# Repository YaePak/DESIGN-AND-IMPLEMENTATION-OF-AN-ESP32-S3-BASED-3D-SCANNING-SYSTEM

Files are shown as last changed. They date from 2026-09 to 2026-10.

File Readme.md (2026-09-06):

# 3D Scanner

## Project Overview

This project focuses on the design and development of a homemade 3D scanner using embedded hardware, distance sensors, motor control systems, and mechanical components.

The main objective is to build a low-cost scanning system capable of collecting distance information from a physical object and converting the collected measurements into three-dimensional data.

The scanner is designed to measure an object from multiple positions while controlling its mechanical movement. The collected measurements can later be processed into a point cloud and used for three-dimensional model reconstruction.

The project is inspired by existing homemade 3D scanner concepts but will be redesigned and developed based on our own hardware, software, mechanical structure, and system architecture.

---

## Why We Chose This Project

We chose the 3D Scanner project because 3D scanning is an interesting technology with practical applications in many fields, including manufacturing, reverse engineering, product design, digital modeling, and object measurement.

Commercial 3D scanners are often expensive and may require complex hardware and specialized software. Therefore, we wanted to explore whether a simpler and lower-cost system could be designed using commonly available components and embedded technology.

Another reason for choosing this project is the engineering challenge of achieving reliable results with limited hardware resources. The performance of the scanner depends not only on the distance sensor, but also on mechanical accuracy, motor positioning, measurement validation, and data processing.

Therefore, this project is not simply about building a scanner. It also provides an opportunity to investigate how hardware limitations, sensor accuracy, mechanical design, and software algorithms affect the quality of the final 3D model.

Our goal is to design and develop a functional prototype while understanding how different engineering components can work together to solve a real-world problem.

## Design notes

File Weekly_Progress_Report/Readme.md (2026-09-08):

# Project Weekly Progress Roadmap

## Project Title

**DESIGN AND IMPLEMENTATION OF AN ESP32-S3-BASED 3D OBJECT SCANNING SYSTEM**

This folder contains the weekly progress reports of the project.

The reports are organized according to the actual development progress of the team. Each week documents the completed tasks, individual responsibilities, current results, problems encountered, and the plan for the following week.

---

## Development Roadmap

### Week 1 – Research and Initial Design

- Research ESP32-S3
- Research Stepper Motor + A4988
- Research TF-Luna
- Develop the system operating principle and algorithm.
- Create the initial 3D mechanical design using Shapr3D.

---

### Week 2 – Hardware Setup and Sensor Testing

- Assemble hardware components
- Set up ESP32-S3 development environment
- Test TF-Luna sensor
- Test Stepper Motor + A4988
- Perform basic calibration and component testing

---

### Week 3 – Motion Control and System Integration

- Verify measurement accuracy and stability.
- Evaluate the sensor performance for 3D scanning.
- Integrate the sensor and motion control system.
- Implement the basic scanning sequence.
- Perform initial scanning tests.

---

### Week 4 – Data Collection and File Generation

- Collect distance and position data.
- Convert the scanning data into coordinate points.
- Generate and store the scanning data file in the ESP32-S3.
- Perform initial scanning tests.

---

### Week 5 – Wi-Fi File Transfer and Data Processing

- Implement Wi-Fi communication.
- Transfer the generated scanning file from the ESP32-S3 to a computer.
- Develop or test the PC-side data receiving process.
- Verify file integrity and scanning data.

---

### Week 6 – 3D Reconstruction

- Scan more complex objects.
- Process the collected point cloud.
- Apply noise filtering and outlier removal.
- Generate the 3D model and evaluate its accuracy.

---

### Week 7 – Final Report and System Testing

- Complete the final technical report.
- Perform complete system testing.
- Verify the overall system performance.
- Prepare the project for final presentation.

---

---

# Team Responsibilities

The project tasks are divided among three main members:

| Member | Student Number | Main Responsibilities |
|---|---|---|
| **Khoa** | 24119048 | Project planning, mechanical assembly, 3D printing, motion testing, Wi-Fi streaming, and 3D reconstruction |
| **Tài** | 24119080 | Electronic components, sensors, ESP32-S3 testing, data processing, filtering, and software documentation |
| **Tuấn** | 24119096 | System architecture, ESP32-S3, motor control, algorithms, and technical reporting | 

---

# Development Phases

The project is divided into the following main phases:

```text
Project Preparation
        ↓
Research and System Assembly
        ↓
Sensor Setup and Calibration
        ↓
Motion Control
        ↓
Sequential Scanning
        ↓
FreeRTOS Multi-Tasking
        ↓
Data Streaming
        ↓
Optimization
        ↓
3D Reconstruction
        ↓
System Validation and Final Report

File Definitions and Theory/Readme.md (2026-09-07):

# System Operating Principle and Algorithm

This section describes the **operating principle and algorithm** of the ESP32-S3-based 3D scanning system.

The system integrates three main components:

* **ESP32-S3** – Main controller of the system.
* **Stepper Motor and A4988 Driver** – Controls the rotational movement of the scanning mechanism.
* **TF-Luna ToF LiDAR Sensor** – Measures the distance between the sensor and the object.

During operation, the ESP32-S3 controls the stepper motor to rotate the object or scanning platform by predefined angular steps. At each position, the TF-Luna sensor measures the distance to the object's surface.

The ESP32-S3 collects and stores the corresponding **distance and angle data**. This process is repeated throughout the scanning cycle to obtain multiple points representing the object's surface.

The collected data can then be used for **Point Cloud Generation** and further **3D Object Reconstruction**.

## Basic Operating Flow

```text
Initialize System
        ↓
Move to Initial Position
        ↓
Rotate by Angular Step
        ↓
Measure Distance
        ↓
Store Distance + Angle
        ↓
Repeat Scanning Process
        ↓
Complete Scan
        ↓
Generate Point Cloud
        ↓
3D Reconstruction
```

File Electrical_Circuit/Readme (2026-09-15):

# PCB Design – ESP32-S3 3D Scanner

## 1. Overview

This section contains the PCB design for the **ESP32-S3-based 3D Scanning System**.

The PCB is designed to integrate the main control and interface circuits of the scanner, including:

* ESP32-S3 N16R8 development module
* 2× A4988 stepper motor drivers
* TF-Luna distance sensor
* Z-axis HOME button
* Power distribution and filtering components
* Motor and sensor connectors

The PCB is designed using **EasyEDA**.

---

## 2. Design Objectives

The main objectives of the PCB are:

* Provide a compact connection between the ESP32-S3 and peripheral modules.
* Control two stepper motors through A4988 drivers.
* Interface the TF-Luna distance sensor using UART.
* Provide a HOME function for the Z-axis.
* Separate motor power from logic power where necessary.
* Reduce wiring complexity compared with a breadboard prototype.
* Provide convenient connectors for motors, power, and external modules.

---

## 3. Main Components

| Component | Quantity | Function |
| --- | ---: | --- |
| ESP32-S3 N16R8 | 1 | Main controller |
| A4988 | 2 | Stepper motor drivers |
| Stepper motor  | 2 | Turntable and Z-axis movement |
| TF-Luna | 1 | Distance measurement |
| Tactile Button | 1 | Z-axis HOME function |
| LED | 1 | Status indication |
| Capacitors | As required | Power filtering |

---

## 4. GPIO Assignment

The current GPIO assignment is:

| Function | ESP32-S3 GPIO |
| --- | ---: |
| Turntable STEP | GPIO4 |
| Turntable DIR | GPIO5 |
| Turntable ENABLE | GPIO6 |
| Z-axis STEP | GPIO10 |
| Z-axis DIR | GPIO11 |
| Z-axis ENABLE | GPIO12 |
| HOME Button | GPIO7 |
| TF-Luna RX | GPIO17 |
| TF-Luna TX | GPIO18 |
| UART0 Debug | GPIO43 / GPIO44 |

### A4988 Control

#### Turntable

```text
ESP32-S3 GPIO4 → STEP
ESP32-S3 GPIO5 → DIR
ESP32-S3 GPIO6 → EN
```

#### Z-axis

```text
ESP32-S3 GPIO10 → STEP
ESP32-S3 GPIO11 → DIR
ESP32-S3 GPIO12 → EN
```

The `EN` input of the A4988 is active-low.

---

## 5. TF-Luna Interface

The TF-Luna is powered from the **5 V supply** and communicates with the ESP32-S3 through UART.

### TF-Luna Pin Connection

| TF-Luna Pin | Function | Connection |
| --- | --- | --- |
| 1 | +5V | 5V |
| 2 | RXD | ESP32-S3 GPIO18 (TX) |
| 3 | TXD | ESP32-S3 GPIO17 (RX) |
| 4 | GND | GND |
| 5 | Configuration | 3.3V / open for UART mode |
| 6 | Multiplexing output | NC |

UART signals are crossed between the sensor and ESP32-S3:

```text
TF-Luna TXD ─────→ ESP32-S3 GPIO17 (RX)
TF-Luna RXD ←───── ESP32-S3 GPIO18 (TX)
```

The TF-Luna power input is connected to the **5 V rail**, while the UART signals are connected to the ESP32-S3 GPIO pins.

---

## 6. Z-axis HOME Button

A tactile push button is used instead of a mechanical limit switch.

The button provides a manual HOME command:

```text
Press HOME button
       ↓
ESP32-S3 detects the button
       ↓
Z-axis moves toward the zero position
       ↓
Z position is set to 0
```

The button is connected using the ESP32-S3 internal pull-up:

```text
GPIO7 ───── Button ───── GND
```

Firmware configuration:

```cpp
pinMode(7, INPUT_PULLUP);
```

Therefore:

* Button released → `HIGH`
* Button pressed → `LOW`

No external pull-up resistor is required.

Software debounce can be implemented in firmware, so an external debounce capacitor is not required for the current design.

---

## 7. Power Design

The PCB contains separate power paths for logic and motors.

### ESP32-S3 / Logic

The ESP32-S3 and logic-level peripherals are supplied from the regulated logic supply.

### TF-Luna

```text
5V → TF-Luna Pin 1
GND → TF-Luna Pin 4
```

### A4988

The A4988 has two different power domains:

* `VDD` → logic supply
* `VMOT` → motor supply

The motor supply must **not** be connected directly to an ESP32-S3 GPIO.

A bulk capacitor should be placed close to the A4988 motor power input to reduce voltage transients generated by the stepper motor.

---

## 8. PCB Design in EasyEDA

The PCB design workflow is:

```text
Schematic
   ↓
Component Assignment
   ↓
PCB Layout
   ↓
Component Placement
   ↓
Routing
   ↓
Design Rule Check (DRC)
   ↓
3D Preview
   ↓
Gerber Generation
```

### Schematic

The schematic defines:

* ESP32-S3 connections
* A4988 control signals
* TF-Luna UART interface
* HOME button
* Power connections
* Motor connectors
* Decoupling and filtering components

### PCB Layout

Components are placed according to their electrical and mechanical requirements.

The A4988 drivers and motor connectors are positioned to keep high-current motor traces away from sensitive sensor and logic connections.

The TF-Luna interface is kept relatively close to the ESP32-S3 to simplify UART routing.

---

## 9. Routing Considerations

The following rules are considered during PCB routing:

* Keep motor power traces short and sufficiently wide.
* Keep GND connections low impedance.
* Place decoupling capacitors close to their corresponding power pins.
* Keep TF-Luna UART traces away from noisy motor power traces when possible.
* Avoid unnecessary long traces for STEP and DIR signals.
* Use a ground plane where appropriate.
* Keep the ESP32-S3 antenna area clear of copper and other components according to the module's layout requirements.

---

## 10. Design Verification

Before manufacturing, the PCB design should be checked for:

* Electrical connectivity
* Incorrect or missing connections
* Short circuits
* Unconnected pins
* GPIO conflicts
* Power polarity
* A4988 power connections
* TF-Luna UART TX/RX direction
* Connector pin assignments
* PCB Design Rule Check (DRC)

The final PCB should also be inspected using EasyEDA's 2D and 3D views before generating the Gerber files.

---

## 11. Tools

### PCB Design Software

**EasyEDA**

Used for:

* Schematic design
* PCB layout
* Component placement
* PCB routing
* Design Rule Check (DRC)
* 3D PCB visualization
* Gerber generation

### Main Development Platform

**ESP32-S3 N16R8**

Used as the main controller of the 3D scanner.

---

## 12. Project Status

Current PCB design includes:

* [x] ESP32-S3 interface
* [x] Two A4988 motor driver interfaces
* [x] TF-Luna UART interface
* [x] Z-axis HOME button
* [x] Power distribution
* [ ] Final PCB routing
* [ ] DRC verification
* [ ] 3D mechanical verification
* [ ] Gerber generation
* [ ] PCB fabrication
* [ ] Hardware testing

---

## 13. Directory Structure

```text
PCB/
├── README.md
├── Schematic/
├── PCB/
├── Gerber/
└── Documentation/
```

The `Schematic/` directory contains the circuit schematic, while the `PCB/` directory contains the EasyEDA PCB layout. Gerber files for manufacturing are stored separately in the `Gerber/` directory.

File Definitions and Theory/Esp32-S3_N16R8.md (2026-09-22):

# ESP32-S3 Microcontroller

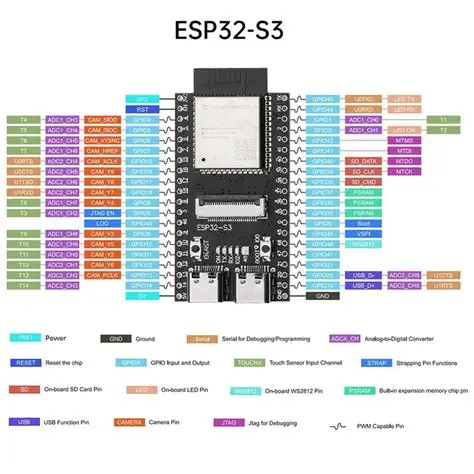
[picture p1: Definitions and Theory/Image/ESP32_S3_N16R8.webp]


The **ESP32-S3** is a high-performance microcontroller developed by Espressif Systems, designed for **IoT (Internet of Things)** and advanced embedded applications.

## Technical Specifications

* **CPU:** Dual-core Xtensa® LX7 processor
* **Clock Frequency:** Up to 240 MHz
* **Operating Voltage:** 3.0 V – 3.6 V (typically 3.3 V)
* **GPIO:** Up to 45 programmable GPIO pins
* **Wireless Connectivity:** Wi-Fi and Bluetooth Low Energy (BLE)
* **Interfaces:** UART, I2C, SPI, PWM, ADC, USB
* **USB:** Native USB support for programming and communication
* **Low-Power Modes:** Supported for energy-efficient applications

## Why ESP32-S3?

The ESP32-S3 was selected for this **3D Scanner project** because it provides high processing performance, a large number of GPIO pins, and multiple hardware interfaces required for connecting sensors and controlling motors.

Its dual-core processor allows the system to handle multiple tasks simultaneously, such as **sensor data acquisition, motor control, and communication**. In addition, the built-in Wi-Fi and BLE provide flexibility for wireless data transmission and remote control.

These features make the ESP32-S3 a suitable and cost-effective solution for developing a **3D object scanning system**.
# ESP32-S3 Microcontroller

The **ESP32-S3** is a high-performance microcontroller developed by Espressif Systems, designed for **IoT (Internet of Things)** and advanced embedded applications.

## Technical Specifications

* **CPU:** Dual-core Xtensa® LX7 processor
* **Clock Frequency:** Up to 240 MHz
* **Operating Voltage:** 3.0 V – 3.6 V (typically 3.3 V)
* **GPIO:** Up to 45 programmable GPIO pins
* **Wireless Connectivity:** Wi-Fi and Bluetooth Low Energy (BLE)
* **Interfaces:** UART, I2C, SPI, PWM, ADC, USB
* **USB:** Native USB support for programming and communication
* **Low-Power Modes:** Supported for energy-efficient applications

## Why ESP32-S3?

The ESP32-S3 was selected for this **3D Scanner project** because it provides high processing performance, a large number of GPIO pins, and multiple hardware interfaces required for connecting sensors and controlling motors.

Its dual-core processor allows the system to handle multiple tasks simultaneously, such as **sensor data acquisition, motor control, and communication**. In addition, the built-in Wi-Fi and BLE provide flexibility for wireless data transmission and remote control.

These features make the ESP32-S3 a suitable and cost-effective solution for developing a **3D object scanning system**.

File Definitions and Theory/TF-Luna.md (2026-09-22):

# Component Description — TF-Luna ToF LiDAR Sensor

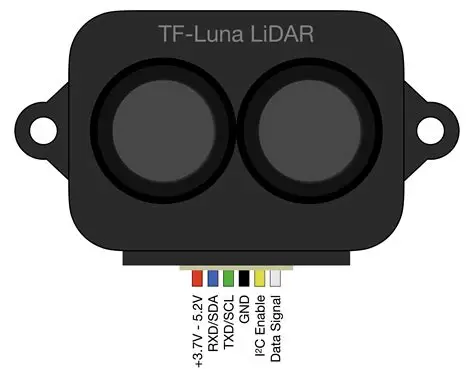
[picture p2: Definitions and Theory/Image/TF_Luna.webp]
TF_Luna


## What It Is

The TF-Luna is a compact, solid-state single-point LiDAR distance sensor made by Benewake. Unlike simple infrared (IR) distance sensors that estimate distance through triangulation of a reflected light spot, the TF-Luna uses the **Time-of-Flight (ToF) principle**: it emits a modulated near-infrared laser pulse and measures the time it takes for the light to reflect off a surface and return to the sensor. That time is then converted directly into a distance value.

## Technical Specifications

| Parameter | Value |
|---|---|
| Measuring principle | Time-of-Flight (ToF) |
| Light source | 850 nm VCSEL laser (Class 1 — eye-safe) |
| Operating range | 0.2 m – 8 m |
| Distance resolution | 1 cm |
| Accuracy | ±6 cm (0.2 m – 3 m), ±2% (3 m – 8 m) |
| Field of View (FOV) | 2° |
| Frame rate | 1 Hz – 250 Hz (100 Hz default, adjustable) |
| Supply voltage | 3.7 V – 5.2 V (5 V typical) |
| Average / peak current | ~70 mA / 150 mA |
| Power consumption | ≤ 0.35 W |
| Communication interface | UART or I2C (UART is the default; I2C must be set manually) |
| Communication level | LVTTL, 3.3 V (directly compatible with ESP32-S3 logic) |
| Default UART baud rate | 115200 |
| Dimensions / weight | 35 × 21.25 × 13.5 mm, < 5 g |
| Operating temperature | −20 °C to 75 °C |

## Why TF-Luna Fits This 3D Scanner Project

The scanner's design compares an IR distance sensor against a ToF sensor as part of its sensor sub-study, and TF-Luna is the ToF side of that comparison:

- **Consistent accuracy over the working range** — because it measures actual light travel time rather than triangulating a reflected spot, its accuracy stays relatively stable across the 0.2 m–8 m range and is less affected by the color or reflectivity of the scanned object's surface than a basic IR sensor is.
- **Narrow 2° field of view** — helps the sensor pick out a single, well-defined point on the object at each turntable angle/Z-height, which matters for building a clean point cloud.
- **Digital UART/I2C output** — the sensor returns a ready-to-use distance value over UART or I2C, so the ESP32-S3 doesn't need to do analog-to-digital conversion or apply a distance-conversion formula, unlike a typical analog IR sensor.
- **Low power and small footprint** — at under 0.35 W and 5 g, it is easy to mount on the scanner's moving Z-axis arm without adding significant load.
- **3.3 V-compatible logic level** — its LVTTL communication level matches the ESP32-S3 directly, simplifying wiring compared to sensors that need level shifting.

In the project's IR-vs-ToF comparison, TF-Luna represents the higher-accuracy, more consistent option, while the IR sensor represents the lower-cost, simpler-interface alternative — letting the report evaluate the practical trade-off between the two for a DIY 3D scanning application.

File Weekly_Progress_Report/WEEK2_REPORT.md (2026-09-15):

## TASKS FOR THIS WEEK

### 1. Adjustment and Improvement of the Mechanical Frame

- Inspect and adjust the mechanical frame to ensure that it is suitable for the object scanning process.
- Optimize the mounting positions of components and mechanical parts to ensure system stability during operation.
- Check the dimensions, structural strength, and movement of the mechanical mechanisms.
- Prepare the mechanical frame for system assembly and 3D scanning tests.

### 2. Component Testing and PCB Soldering

- Inspect the condition and specifications of the components before assembly.
- Test the functionality of the components to identify any defective or unsuitable components.
- Solder the components onto the PCB according to the circuit design.
- Inspect the quality of the solder joints and the connections between the components and the PCB after soldering.
- Perform an initial inspection and functional test of the PCB to ensure that it operates properly and is ready for system integration.

### Objectives

Complete and optimize the mechanical frame to meet the requirements of object scanning, while completing component testing and PCB assembly to prepare for the system integration, operation, and testing phase.

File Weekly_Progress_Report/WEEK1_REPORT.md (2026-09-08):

# 3. Member Responsibilities and Completed Tasks

## Huynh Anh Tuan - 24119096 – ESP32-S3 and System Control

### Assigned Tasks

- Research the ESP32-S3 microcontroller.
- Analyze its technical specifications and hardware interfaces.
- Determine the role of the ESP32-S3 in the system.
- Develop the overall system operating principle and algorithm.

### Completed Tasks

- Completed the ESP32-S3 technical documentation.
- Analyzed the processor, GPIO, operating voltage, and communication interfaces.
- Defined the ESP32-S3 as the main controller of the 3D scanning system.
- Developed the basic system operating principle and operating algorithm.

### Status

**Completed**

---

## Le Thanh Tai - 24119080 – Motor Control and Distance Measurement

### Assigned Tasks

- Research the Stepper Motor and A4988 Driver.
- Study the motor control mechanism using STEP and DIR signals.
- Research the TF-Luna ToF LiDAR sensor.
- Analyze the distance measurement principle and its application in 3D scanning.

### Completed Tasks

- Completed the Stepper Motor and A4988 Driver documentation.
- Studied the STEP and DIR control mechanism.
- Completed the TF-Luna technical documentation.
- Analyzed the Time-of-Flight (ToF) distance measurement principle.
- Defined how distance data can be collected during the scanning process.

### Status

**Completed**

---

## Phan Anh Khoa - 24119048 – 3D Mechanical Design

### Assigned Tasks

- Design the mechanical structure of the 3D scanning system.
- Create the initial 3D model of the scanner.
- Design the frame and component mounting structure.
- Prepare the design for 3D printing.

### Completed Tasks

- Completed the initial mechanical design of the 3D scanner.
- Designed the structural frame using Shapr3D.
- Created the Front View of the mechanical model.
- Created the Isometric View of the complete design.
- Prepared the mechanical structure for further development and 3D printing.

### Status

**Completed**

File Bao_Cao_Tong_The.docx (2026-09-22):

BỘ GIÁO DỤC VÀ ĐÀO TẠO
TRƯỜNG ĐẠI HỌC SƯ PHẠM KỸ THUẬT TP. HỒ CHÍ MINH
KHOA ĐIỆN – ĐIỆN TỬ
BỘ MÔN KỸ THUẬT MÁY TÍNH – VIỄN THÔN

------------------***------------------

BÁO CÁO ĐỒ ÁN HỆ THỐNG NHÚNG

NGHIÊN CỨU, THIẾT KẾ VÀ THI CÔNG HỆ THỐNG MÁY QUẾT 3D NHÚNG DỰA TRÊN VI ĐIỀU KHIỂN ESP32-S3 VÀ CẢM BIẾN LIDAR TF-LUNA

GVHD: ThS. Huỳnh Hoàng Hà

SVTH 1: Huỳnh Anh Tuấn MSSV: 24119096
SVTH 2: Lê Thanh Tài MSSV: 24119080
SVTH 3: Phan Anh Khoa MSSV: 24119048

Ngành: Công nghệ Kỹ thuật Máy tính
Lớp: Thiết kế Hệ thống Nhúng

TP. HỒ CHÍ MINH – NĂM 2026

MỤC LỤC & DÀN Ý TỔNG QUAN 5 CHƯƠNG CỦA ĐỒ ÁN

Theo chuẩn mực của đồ án kỹ thuật thuộc ngành Công nghệ Kỹ thuật Máy tính, báo cáo đề tài "Nghiên cứu, Thiết kế và Thi công Hệ thống Máy quét 3D Nhúng" được cấu trúc thống nhất thành 5 chương chính. Bố cục này đi từ việc xác lập bối cảnh, mục tiêu, cơ sở lý thuyết toán học/phần cứng, đến quy trình phân tích thiết kế, thi công thực nghiệm và đánh giá kết quả sản phẩm.

📌 CẤU TRÚC BÁO CÁO 5 CHƯƠNG CHUẨN ĐỒ ÁN HỆ THỐNG NHÚNG

• Chương 1: Giới thiệu tổng quan đề tài, tính cấp thiết, mục tiêu, đối tượng, phạm vi và phương pháp nghiên cứu.

• Chương 2: Cơ sở lý thuyết nền tảng (Lý thuyết tọa độ trụ, vi điều khiển ESP32-S3, FreeRTOS Dual-Core, ToF LiDAR TF-Luna, động cơ bước NEMA17/A4988, WiFi TCP Socket và thuật toán xuất file STL).

• Chương 3: Phân tích & Thiết kế hệ thống (Đặc tả FR/NFR, sơ đồ khối, sơ đồ nguyên lý mạch Schematic, PCB 2 lớp, kiến trúc FreeRTOS Dual-Core và phần mềm PC).

• Chương 4: Thi công & Thực nghiệm đánh giá (Lắp ráp cơ khí 3D, nạp firmware, hiệu chuẩn dải đo FLUX, kiểm thử WiFi TCP, quét mẫu thực tế và đánh giá sai số).

• Chương 5: Kết luận & Hướng phát triển (Tổng kết kết quả đạt được, chỉ ra các hạn chế và đề xuất phương hướng nâng cấp).

Chương | Tên Chương | Trọng Tâm Nội Dung Chi Tiết
Chương 1 | GIỚI THIỆU | Lý do chọn đề tài, tính cấp thiết, mục tiêu tổng quát/cụ thể, đối tượng, phạm vi, phương pháp nghiên cứu và đóng góp thực tiễn.
Chương 2 | CƠ SỞ LÝ THUYẾT | Lý thuyết tọa độ trụ, biến đổi Cartesian, vi điều khiển ESP32-S3, FreeRTOS Dual-Core, LiDAR TF-Luna ToF, A4988/NEMA17, WiFi TCP Socket, thuật toán dựng lưới STL.
Chương 3 | THIẾT KẾ HỆ THỐNG | Sơ đồ khối hệ thống, đặc tả FR/NFR, sơ đồ nguyên lý mạch (Schematic), thiết kế PCB 2 lớp, kiến trúc phần mềm nhúng FreeRTOS (Core 1 / Core 0 / Queue), ứng dụng PC Receiver.
Chương 4 | THI CÔNG & THỰC NGHIỆM | Thi công khung cơ khí in 3D, hàn ráp mạch, thử nghiệm hiệu chuẩn dải tín hiệu FLUX, kiểm thử kết nối không dây, tiến hành quét mẫu vật thể và đánh giá sai số kích thước STL.
Chương 5 | KẾT LUẬN & HƯỚNG PHÁT TRIỂN | Đánh giá mức độ hoàn thành so với mục tiêu ban đầu, phân tích hạn chế của máy quét và đề xuất cải tiến (tăng tốc độ quét, thiết kế PCB công nghiệp, lọc mượt nâng cao).

CHƯƠNG 1: GIỚI THIỆU

1.1. Lý do chọn đề tài và tính cấp thiết

Trong kỷ nguyên Cách mạng Công nghiệp 4.0, công nghệ dựng hình và mô hình hóa 3D (3D Scanning / Point Cloud Reconstruction) đóng vai trò ngày càng then chốt trong nhiều lĩnh vực kỹ thuật hiện đại như chế tạo cơ khí chính xác, y tế (thiết kế chi giả, chỉnh hình), bảo tồn di sản văn hóa, kiểm tra chất lượng sản phẩm (Quality Control) và tích hợp vào các hệ thống thực tế ảo (AR/VR). Khả năng số hóa chính xác hình học không gian của một vật thể thực thành dữ liệu đám mây điểm ba chiều giúp rút ngắn đáng kể thời gian thiết kế ngược (Reverse Engineering) và tối ưu hóa quy trình sản xuất.

Tuy nhiên, việc tiếp cận công nghệ quét 3D trong thực tế sản xuất nhỏ và học tập nghiên cứu tại Việt Nam hiện nay đang gặp phải hai rào cản chính:

1. Chi phí đầu tư thiết bị thương mại cực kỳ cao: Các máy quét 3D chuyên dụng nhập khẩu (sử dụng công nghệ quét laser hoặc ánh sáng cấu trúc) thường có giá thành từ vài ngàn đến hàng chục ngàn USD. Bên cạnh đó, các máy quét thương mại này đi kèm với phần mềm đóng thương quyền, chi phí bảo trì đắt đỏ và không cho phép tùy biến thuật toán phục vụ nghiên cứu.

2. Hạn chế của các mô hình máy quét 3D tự làm (DIY/Open-source) truyền thống: Nhiều thiết kế máy quét 3D tự làm trên internet (chẳng hạn như mô hình máy quét sử dụng Arduino Nano và cảm biến hồng ngoại Sharp GP2Y0A51SK0F) bộc lộ rất nhiều nhược điểm kỹ thuật nghiêm trọng. Cảm biến hồng ngoại analog có độ nhiễu tín hiệu rất cao, phụ thuộc mạnh vào màu sắc và độ bóng của bề mặt vật thể, dải đo rất hẹp (2cm - 15cm) và có sai số phi tuyến lớn. Ngoài ra, vi điều khiển 8-bit như Arduino Nano/Uno có dung lượng bộ nhớ RAM cực kỳ hạn chế (2KB), tần số xử lý thấp (16MHz), không hỗ trợ xử lý đa nhiệm thời gian thực và phải lưu tạm dữ liệu điểm vào thẻ nhớ SD một cách thủ công, gây gián đoạn và làm kéo dài thời gian quét.

Xuất phát từ các rào cản thực tế nêu trên, đề tài “Nghiên cứu, Thiết kế và Thi công Hệ thống Máy quét 3D Nhúng dựa trên Vi điều khiển ESP32-S3 và Cảm biến LiDAR TF-Luna” được triển khai nhằm mang lại một giải pháp cải tiến vượt trội. Đề tài kết hợp sức mạnh xử lý của vi điều khiển lõi kép ESP32-S3 (tần số 240MHz, tích hợp WiFi/Bluetooth), cảm biến đo khoảng cách chính xác bằng công nghệ Time-of-Flight (ToF LiDAR TF-Luna), kỹ thuật điều khiển vi bước (Microstepping 1/16) động cơ NEMA17 qua driver A4988, hệ điều hành đa nhiệm thời gian thực FreeRTOS và giao thức truyền luồng dữ liệu thời gian thực qua mạng không dây WiFi TCP/IP Socket tới máy tính. Giải pháp này cho phép tạo ra một thiết bị quét 3D nhúng nhỏ gọn, chi phí thấp, độ chính xác cao và khả năng tự động dựng mô hình 3D STL khép kín.

1.2. Mục tiêu nghiên cứu

1.2.1. Mục tiêu tổng quát

Nghiên cứu, thiết kế, thi công và đánh giá thực nghiệm một hệ thống máy quét 3D nhúng hoàn chỉnh, có khả năng tự động hóa chu trình quét các vật thể nhỏ dạng hình học phức tạp, thu thập dữ liệu đám mây điểm thời gian thực, truyền nhận không dây qua WiFi TCP/IP và xử lý hậu kỳ trên phần mềm máy tính để xuất tệp tin mô hình 3D chuẩn định dạng STL nhị phân khép kín (watertight).

1.2.2. Mục tiêu cụ thể

Để đạt được mục tiêu tổng quát, đề tài xác lập 5 nhiệm vụ kỹ thuật cụ thể sau:

• Nghiên cứu cơ sở lý thuyết: Nghiên cứu nguyên lý quét 3D theo không gian tọa độ trụ, lý thuyết cảm biến ToF LiDAR TF-Luna, cơ chế điều khiển động cơ bước NEMA17/A4988 và toán học dựng lưới hình học 3D.

• Thiết kế phần cứng hệ thống nhúng: Tính toán công suất nguồn, vẽ sơ đồ mạch nguyên lý (Schematic) kết nối ESP32-S3 với cảm biến TF-Luna (I2C/UART), 2 driver A4988, nút bấm Start và công tắc hành trình Z-Limit; thiết kế và thi công bo mạch PCB 2 lớp nhỏ gọn.

• Xây dựng phần mềm nhúng đa nhiệm FreeRTOS: Lập trình firmware C++ trên ESP32-S3 sử dụng kiến trúc FreeRTOS Dual-Core (Nhân 1 dành riêng cho tác vụ thời gian thực điều khiển motor và đọc cảm biến; Nhân 0 dành riêng cho WiFi TCP stack và truyền dữ liệu qua hàng đợi Queue).

• Xây dựng phần mềm PC & Thuật toán dựng hình: Phát triển chương trình Python trên PC lắng nghe kết nối socket TCP cổng 5000, nhận luồng tọa độ thời gian thực, thực hiện bộ lọc nhiễu FLUX, nội suy tuyến tính lấp lỗ trống, lọc mượt bề mặt 3x3 và xuất file STL nhị phân.

• Thi công cơ khí & Thực nghiệm đánh giá: Lắp ráp khung máy quét in 3D cơ động, tiến hành kiểm thử hiệu chuẩn cảm biến, thực nghiệm quét các mẫu vật thể thực tế và đo đạc sai số kích thước so với vật thể gốc.

1.3. Đối tượng và phạm vi nghiên cứu

1.3.1. Đối tượng nghiên cứu

Đối tượng nghiên cứu trọng tâm của đề tài bao gồm hai phần chính:

1. Phần cứng hệ thống nhúng: Nghiên cứu vi điều khiển lõi kép ESP32-S3, cảm biến ToF LiDAR TF-Luna, driver A4988, động cơ bước NEMA17, công tắc hành trình giới hạn trục Z và mạch nguồn hạ áp ổn định.

2. Phần mềm nhúng và thuật toán xử lý không gian 3D: Nghiên cứu hệ điều hành FreeRTOS đa nhiệm trên ESP32-S3, phương thức truyền thông WiFi TCP Socket, thuật toán chuyển đổi tọa độ trụ sang Cartesian, thuật toán nội suy lấp lỗ trống (Interpolation), bộ lọc mượt 3x3 và kỹ thuật dựng lưới xuất file STL nhị phân.

1.3.2. Phạm vi nghiên cứu

Đề tài giới hạn phạm vi thực hiện trong các thông số kỹ thuật sau:

• Kích thước vật thể quét: Thiết bị được thiết kế tối ưu để quét các vật thể nhỏ có chiều cao Z ≤ 150 mm và bán kính R ≤ 150 mm.

• Khoảng cách đặt cảm biến: Khoảng cách từ vị trí phát cảm biến TF-Luna đến tâm bàn xoay được cố định ở mức 28 cm.

• Hạ tầng mạng truyền thông: Sử dụng mạng WiFi Access Point (AP Mode) do chính ESP32-S3 tự phát để tạo kênh truyền dữ liệu nội bộ với PC trong dải bán kính 10 mét.

• Định dạng đầu ra: Sản phẩm phần mềm xuất ra tệp tin mô hình 3D tiêu chuẩn dạng STL nhị phân (Binary STL) có thể mở trực tiếp trên các phần mềm cắt lớp in 3D (Cura, PrusaSlicer) hoặc phần mềm thiết kế 3D (MeshLab, Blender).

1.4. Phương pháp nghiên cứu

Đề tài áp dụng quy trình nghiên cứu khoa học hệ thống, kết hợp giữa nghiên cứu lý thuyết chuyên sâu, thiết kế mô hình hóa phần cứng và thực nghiệm đo đạc thực tế. Các phương pháp cụ thể bao gồm:

• Phương pháp nghiên cứu tài liệu & Datasheet: Thu thập, phân tích các tài liệu kỹ thuật về kiến trúc ESP32-S3, giao thức giao tiếp I2C/UART của cảm biến TF-Luna, tập lệnh FreeRTOS và chuẩn tệp tin STL.

• Phương pháp thiết kế & Module hóa hệ thống nhúng: Phân chia hệ thống thành các khối chức năng độc lập (Khối nguồn, Khối xử lý trung tâm, Khối cảm biến, Khối chấp hành động cơ, Khối truyền thông) để thiết kế mạch nguyên lý và sơ đồ PCB.

• Phương pháp lập trình thời gian thực: Sử dụng môi trường VS Code / PlatformIO với ngôn ngữ C++ để lập trình đa nhiệm FreeRTOS trên ESP32-S3, ứng dụng hàng đợi Queue để cách ly hoàn toàn nhịp điều khiển động cơ khỏi độ trễ WiFi.

• Phương pháp toán học & Xử lý tín hiệu không gian: Xây dựng các công thức biến đổi hình học không gian, bộ lọc tín hiệu FLUX triệt tiêu nhiễu phản xạ và thuật toán dựng lưới tam giác bề mặt kín.

• Phương pháp thực nghiệm & Đo đạc sai số: Tiến hành quét thử nghiệm các hình khối chuẩn (hình trụ, hình hộp, mô hình tượng) và đối chiếu kích thước thu được với thước kẹp kỹ thuật số để tính toán sai số phần trăm (%).

1.5. Ý nghĩa khoa học và thực tiễn

1.5.1. Ý nghĩa khoa học

• Khẳng định tính hiệu quả của kiến trúc hệ điều hành đa nhiệm thời gian thực FreeRTOS Dual-Core trong việc xử lý các bài toán nhúng phức tạp, yêu cầu độ chính xác thời gian cao (tạo xung vi bước microseconds) kết hợp với truyền thông không dây tốc độ cao mà không làm gián đoạn hệ thống.
• Xây dựng và kiểm chứng hoàn chỉnh chuỗi thuật toán xử lý dữ liệu đám mây điểm thô (Point Cloud Processing Pipeline) từ khâu thu thập, lọc nhiễu, nội suy không gian đến dựng lưới hình học 3D khép kín hoàn toàn bằng mã nguồn mở Python.

1.5.2. Ý nghĩa thực tiễn

• Tạo ra một thiết bị máy quét 3D nhúng có chi phí chế tạo rẻ (chỉ bằng dưới 5% so với máy quét thương mại), dễ dàng tiếp cận cho sinh viên, nghiên cứu sinh và các xưởng sản xuất nhỏ phục vụ công tác học tập và thiết kế ngược.
• Cung cấp một tệp giải pháp phần cứng và phần mềm nhúng mở, có khả năng tùy biến cao, mở ra hướng ứng dụng trong tích hợp robot, kiểm tra sản phẩm tự động hoặc kết hợp với công nghệ in 3D chế tạo nhanh.

CHƯƠNG 2: CƠ SỞ LÝ THUYẾT VÀ NỀN TẢNG CÔNG NGHỆ

2.1. Tổng quan về công nghệ quét 3D và nguyên lý quét theo tọa độ trụ

2.1.1. Khái niệm về đám mây điểm (Point Cloud) và dựng hình 3D

Đám mây điểm (Point Cloud) là một tập hợp các điểm dữ liệu trong không gian ba chiều, được xác định bởi các tọa độ toán học (x, y, z). Trong các hệ thống số hóa không gian, đám mây điểm biểu diễn bề mặt bên ngoài của một vật thể thực. Mỗi điểm trong tập hợp đại diện cho một vị trí phản xạ ánh sáng hoặc sóng đo được từ bề mặt vật thể tới cảm biến. Để chuyển đổi tập hợp các điểm rời rạc này thành mô hình 3D liên tục có thể xử lý trên phần mềm CAD/CAM, hệ thống cần thực hiện quá trình dựng lưới bề mặt (Mesh Generation) bằng cách nối các điểm lân cận thành các mặt tam giác phẳng nhỏ (Polygon Mesh).

2.1.2. Nguyên lý quét 3D theo không gian tọa độ trụ (r, θ, z)

Thay vì sử dụng các hệ thống quang học quét hai chiều phức tạp, đề tài áp dụng nguyên lý quét mở rộng theo không gian tọa độ trụ (Cylindrical Coordinate System). Vật thể cần quét được đặt tại tâm của một bàn xoay tròn. Cảm biến đo khoảng cách ToF LiDAR được cố định trên một bàn nâng di chuyển theo chiều đứng (trục Z) và hướng thẳng vào tâm quay của bàn xoay.

Quá trình quét được thực hiện theo từng lớp độ cao (Layer-by-Layer):
1. Tại mỗi lớp độ cao Z cố định, động cơ bàn xoay tăng góc quay θ theo từng bước cố định, chia trọn một vòng quay (360°) thành N mẫu góc đều nhau.
2. Tại mỗi vị trí góc θ, cảm biến LiDAR TF-Luna đo khoảng cách d từ cảm biến tới bề mặt vật thể.
3. Gọi L là khoảng cách cố định từ cảm biến tới tâm quay của bàn xoay (trong hệ thống được thiết lập L = 28 cm). Bán kính r của vật thể tại góc quay θ được xác định theo công thức:

r = L - d

2.1.3. Công thức toán học chuyển đổi sang hệ tọa độ Đề-các (x, y, z)

Để hiển thị và xử lý hình học trên máy tính, tập dữ liệu tọa độ trụ (r, θ, z) thu được tại mỗi điểm quét được chuyển đổi sang hệ tọa độ vuông góc Đề-các (Cartesian Coordinates x, y, z) theo các công thức lượng giác cơ bản:

x = r · cos(θ)
y = r · sin(θ)
z = index_layer · layer_height

Trong đó: index_layer là chỉ số lớp quét hiện tại (0, 1, 2, ...), và layer_height là chiều cao nâng của trục Z tại mỗi lớp (ví dụ: 1.0 mm).

2.2. Nghiên cứu vi điều khiển ESP32-S3 và kiến trúc phần mềm FreeRTOS Dual-Core

2.2.1. Đặc tính kỹ thuật của vi điều khiển lõi kép ESP32-S3

Vi điều khiển ESP32-S3 (Espressif Systems) là một System-on-Chip (SoC) mạnh mẽ, được thiết kế chuyên biệt cho các ứng dụng IoT và hệ thống nhúng đòi hỏi hiệu năng cao. Trái tim của ESP32-S3 là bộ vi xử lý lõi kép Xtensa® 32-bit LX7 với tần số xung nhịp lên tới 240 MHz. Chip sở hữu 512 KB SRAM nội bộ, tích hợp sẵn các giao thức kết nối không dây WiFi 802.11 b/g/n (2.4 GHz) và Bluetooth 5.0 (LE). Ngoài ra, ESP32-S3 còn hỗ trợ mở rộng bộ nhớ Flash/PSRAM ngoài qua giao tiếp SPI tốc độ cao và tích hợp bộ tăng tốc phần cứng cho các phép toán số học vector và mã hóa bảo mật.

2.2.2. Kiến trúc phần mềm đa nhiệm FreeRTOS và bài toán thời gian thực

Trong các hệ thống nhúng truyền thống chạy đơn luồng (Single-thread loop), việc kết hợp giữa việc tạo xung điều khiển động cơ bước (yêu cầu độ chính xác thời gian tính bằng microsecond) với việc truyền dữ liệu qua mạng WiFi thường gây ra xung đột nghiêm trọng. WiFi Protocol Stack trên vi điều khiển có độ trễ truyền tin không xác định (unpredictable latency), khiến chương trình bị chặn (blocking) trong lúc chờ gửi gói tin mạng. Nếu chạy tuần tự trong cùng một vòng lặp, độ trễ này sẽ làm trễ nhịp phát xung động cơ, gây ra hiện tượng rung giật, mất bước động cơ và làm sai lệch khoảng cách đo cảm biến.

Để giải quyết triệt để bài toán thời gian thực này, đề tài ứng dụng hệ điều hành đa nhiệm thời gian thực FreeRTOS (được tích hợp sẵn trong ESP-IDF / PlatformIO). FreeRTOS cho phép chia nhỏ chương trình thành các tác vụ (Tasks) độc lập, được quản lý bởi bộ lập lịch theo độ ưu tiên (Priority-based Preemptive Scheduler).

2.2.3. Cơ chế phân chia tác vụ Dual-Core (Core 1 vs. Core 0) và hàng đợi FreeRTOS Queue

Firmware trên ESP32-S3 được thiết kế phân chia triệt để công việc lên 2 nhân xử lý vật lý của chip:

• Core 1 (Thời gian thực - Real-time Core): Đảm nhiệm duy nhất tác vụ điều khiển chuyển động và đọc cảm biến (`motorTask`). Nhân này thực hiện phát xung vi bước A4988 điều khiển bàn xoay, đọc khoảng cách từ cảm biến TF-Luna qua I2C/UART, thực hiện bộ lọc tín hiệu FLUX ban đầu và đẩy kết quả hợp lệ vào hàng đợi trung gian.

• Core 0 (Truyền thông - Communication Core): Đây là nhân mà WiFi Protocol Stack của ESP32-S3 luôn cố định chạy. Core 0 đảm nhiệm tác vụ truyền thông (`commTask`), liên tục kiểm tra và lấy dữ liệu điểm từ hàng đợi FreeRTOS Queue, đóng gói gói tin và gửi qua mạng WiFi TCP Socket tới máy tính.

Hai nhân giao tiếp với nhau thông qua một hàng đợi FreeRTOS Queue (`rawQueue`) có kích thước bộ đệm 256 phần tử. Nhờ cơ chế hàng đợi bộ đệm an toàn này, tác vụ tạo xung motor trên Core 1 hoạt động với chu kỳ thời gian thực tuyệt đối mà không bao giờ bị ảnh hưởng hay gián đoạn bởi độ trễ truyền dữ liệu WiFi trên Core 0.

📌 SƠ ĐỒ PHÂN CHIA TÁC VỤ DUAL-CORE TRÊN ESP32-S3

• Core 1: Chạy motorTask (Độ ưu tiên cao) -> Điều khiển A4988 + Đọc TF-Luna -> Đẩy vào rawQueue.

• FreeRTOS rawQueue: Bộ đệm liên nhân (Thread-safe Queue, 256 phần tử) cách ly hai luồng xử lý.

• Core 0: Chạy commTask (Độ ưu tiên trung bình) + WiFi Stack -> Lấy từ rawQueue -> Gửi qua WiFi TCP Socket.

2.3. Cảm biến ToF LiDAR TF-Luna và cơ chế lọc tín hiệu FLUX

2.3.1. Nguyên lý đo khoảng cách ToF (Time-of-Flight) bằng tia hồng ngoại

Cảm biến TF-Luna (SJ-PM-TF-Luna) hoạt động dựa trên nguyên lý Time-of-Flight (ToF) phát xung ánh sáng không nhìn thấy. Cảm biến phát ra các xung ánh sáng hồng ngoại bước sóng 850nm hướng tới bề mặt vật thể. Ánh sáng phản xạ từ vật thể quay trở lại và được thu nhận bởi bộ cảm biến quang học tích hợp bên trong. Khoảng cách d từ cảm biến tới bề mặt vật thể được tính toán dựa trên khoảng thời gian t mà xung ánh sáng đi và về:

d = (c · t) / 2

Trong đó c là tốc độ ánh sáng trong không khí (c ≈ 3·10^8 m/s). So với cảm biến hồng ngoại Tam giác đạc (Triangulation) truyền thống, nguyên lý ToF cho phép đo khoảng cách chính xác, ít bị ảnh hưởng bởi màu sắc, độ phản xạ của bề mặt vật thể và có tốc độ đáp ứng cực nhanh.

2.3.2. Thông số kỹ thuật và phương thức giao tiếp của cảm biến TF-Luna

Cảm biến TF-Luna sở hữu các thông số kỹ thuật ấn tượng phù hợp cho thiết bị quét 3D nhúng:

• Dải đo khoảng cách: 0.2 mét – 8.0 mét (trong điều kiện trong nhà).

• Độ chính xác đo: ±2 cm (trong dải 0.2m - 3m).

• Độ phân giải khoảng cách: 1 cm.

• Tần số trích mẫu (Frame Rate): Có thể cấu hình linh hoạt từ 1 Hz đến 250 Hz (mặc định 100 Hz).

• Góc nhìn (FOV): 2° (chùm tia hội tụ hẹp, rất lý tưởng để quét chi tiết điểm nhỏ).

• Giao thức kết nối: Hỗ trợ cả giao diện UART (3.3V TTL, Baudrate 115200) và giao diện I2C (Address 0x10).

• Điện áp hoạt động: 5V DC, dòng tiêu thụ trung bình ≤ 70 mA.

2.3.3. Thuật toán lọc nhiễu khoảng cách dựa trên ngưỡng cường độ phản xạ FLUX

Trong mỗi gói dữ liệu đo trả về, ngoài giá trị khoảng cách Distance (cm), cảm biến TF-Luna còn cung cấp chỉ số FLUX (Cường độ tín hiệu ánh sáng phản xạ thu được). Chỉ số FLUX phản ánh độ tin cậy của phép đo:

• Khi dùm tia rọi vào không trung hoặc vượt khỏi đỉnh vật thể, tín hiệu phản xạ rất yếu (FLUX rất nhỏ, gần bằng 0).
• Khi dùm tia đập vào bề mặt vật thể thực, FLUX thu được có giá trị cao (thường từ vài trăm đến hàng ngàn đơn vị).

Firmware trên ESP32-S3 tích hợp thuật toán lọc nhiễu ngưỡng FLUX động. Phép đo chỉ được coi là hợp lệ khi thỏa mãn điều kiện:

FLUX ≥ TFL_MIN_VALID_FLUX

Thông qua các thử nghiệm thực tế với script `checkFLUX`, ngưỡng `TFL_MIN_VALID_FLUX` được thiết lập ở mức 100 đơn vị. Các điểm đo có FLUX < 100 sẽ lập tức bị loại bỏ, giúp triệt tiêu hoàn toàn các điểm nhiễu rác ngoài không gian xung quanh vật thể.

2.4. Động cơ bước NEMA17 và Trình điều khiển Driver A4988

2.4.1. Nguyên lý cấu tạo và điều khiển của Động cơ bước NEMA17

Động cơ bước (Stepper Motor) là một loại động cơ điện đồng bộ, chuyển đổi các xung điện kỹ thuật số thành các chuyển động cơ học góc quay góc bước cố định. Đề tài sử dụng 2 động cơ bước NEMA17 2 pha lưỡng cực (Bipolar Stepper Motor), có góc bước cơ bản là 1.8°/bước (tương ứng 200 bước/vòng quay trọn 360°):
• Động cơ 1: Điều khiển quay trục bàn xoay chứa vật thể.
• Động cơ 2: Điều khiển vít me nâng hạ bàn nâng chứa cảm biến LiDAR theo trục đứng Z.

2.4.2. Mạch điều khiển A4988 và kỹ thuật vi bước (Microstepping 1/16)

Để điều khiển động cơ bước NEMA17, hệ thống sử dụng mạch driver chuyên dụng A4988 (Allegro MicroSystems). A4988 tích hợp bộ dịch tự động (Translator) giúp đơn giản hóa việc giao tiếp với vi điều khiển: chỉ cần 2 chân tín hiệu chính là STEP và DIR.

Đặc biệt, A4988 hỗ trợ công nghệ vi bước (Microstepping) cho phép chia nhỏ 1 bước cơ bản (1.8°) thành các vi bước nhỏ hơn: 1/2, 1/4, 1/8 và 1/16 bước. Hệ thống được cấu hình chạy ở chế độ vi bước tối đa 1/16 (bằng cách nối mức cao 3.3V vào cả 3 chân MS1, MS2, MS3):
• Khi chạy vi bước 1/16, một vòng quay 360° của bàn xoay được chia thành 200 × 16 = 3200 vi bước.
• Vi bước giúp bàn xoay di chuyển cực kỳ mịn, không bị giật bước cơ học, giảm độ rung lắc vật thể khi quay và nâng cao độ phân giải góc quét.

2.4.3. Phương pháp phát xung STEP/DIR điều khiển bàn xoay và nâng hạ trục Z

Phương pháp phát xung trên ESP32-S3 được thực hiện thông qua việc điều khiển chân GPIO cấp cho A4988:
• Tín hiệu DIR: Thiết lập mức HIGH/LOW để xác định chiều quay (thuận/ngược chiều kim đồng hồ).
• Tín hiệu STEP: Tạo một xung vuông (Tần số xung quyết định tốc độ quay). Mỗi sườn lên (Rising edge) của xung STEP làm động cơ nhích đúng 1 vi bước.

Thời gian trễ xung `STEP_DELAY_US` giữa hai mức HIGH và LOW được tối ưu hóa ở mức 200–300 microseconds, đảm bảo động cơ quay mượt mà, đạt momen xoắn ổn định mà không bị bỏ bước (missed steps).

2.5. Giao thức truyền thông WiFi TCP Socket và cơ chế truyền luồng dữ liệu thời gian thực

2.5.1. Khởi tạo mạng WiFi Access Point (AP Mode) trên ESP32-S3

Để đảm bảo thiết bị máy quét 3D có thể vận hành độc lập ở bất kỳ đâu mà không phụ thuộc vào hạ tầng mạng Internet hay router WiFi ngoài, firmware cấu hình ESP32-S3 hoạt động ở chế độ WiFi Access Point (SoftAP Mode):
• Tên mạng SSID phát ra: `ScannerESP32`
• Mật khẩu kết nối: `12345678`
• Địa chỉ IP mặc định của máy quét: `192.168.4.1`

2.5.2. Giao thức mạng TCP/IP Socket và mô hình Server-Client

Hệ thống thiết lập kênh truyền thông mạng theo mô hình TCP Server - TCP Client dựa trên giao thức TCP/IP (Transmission Control Protocol):
• Trên ESP32-S3: Khởi tạo một TCP Server lắng nghe kết nối tại cổng mạng 5000 (`WiFiServer server(5000)`).
• Trên Máy tính (PC): Chạy ứng dụng Python `pc_receiver.py` kết nối tới WiFi `ScannerESP32` và đóng vai trò TCP Client mở Socket kết nối tới `192.168.4.1:5000`.

2.5.3. Ưu điểm của truyền dữ liệu qua Socket so với lưu trữ thẻ SD

So với giải pháp ghi dữ liệu vào thẻ nhớ SD của các máy quét 3D truyền thống, giải pháp truyền luồng WiFi TCP Socket có những ưu điểm vượt trội:

• Truyền dữ liệu thời gian thực (Real-time Streaming): Mỗi điểm tọa độ (x, y, z) ngay khi vừa được tính toán xong sẽ lập tức được truyền về máy tính, cho phép người dùng quan sát tiến độ quét trực quan trên màn hình.

• Độ tin cậy và toàn vẹn dữ liệu cao: Giao thức TCP có cơ chế bắt tay 3 bước (3-way handshake), kiểm lỗi và gửi lại gói tin (ACK/Retransmission), đảm bảo không một điểm dữ liệu nào bị mất hay sai lệch trên đường truyền không dây.

• Khắc phục rào cản tốc độ ghi phần cứng: Không bị giới hạn bởi tốc độ ghi I/O chậm của thẻ nhớ SD hay nguy cơ hỏng tệp tin khi sút nguồn giữa chừng.

2.6. Thuật toán dựng lưới hình học và xuất tệp tin mô hình 3D STL

2.6.1. Cấu trúc lưới đều (Regular Grid Mesh) từ dữ liệu quét hai chiều

Do nguyên lý quét được thực hiện theo từng lớp Z cố định và tại mỗi lớp, bàn xoay quay các góc θ_i cố định chia đều vòng quay, tập dữ liệu đám mây điểm thu được mang một cấu trúc hình học cực kỳ đặc biệt: Cấu trúc lưới chữ nhật đều hai chiều (2D Regular Grid Matrix). Mỗi điểm quét được định vị duy nhất bởi cặp chỉ số (i, j) trong đó i là chỉ số góc quay (i = 0 ... N-1) và j là chỉ số lớp quét (j = 0 ... M-1).

2.6.2. Thuật toán nội suy lấp lỗ trống (Linear Interpolation)

Trong quá trình quét thực tế, một số điểm đo có thể bị loại bỏ do vượt quá ngưỡng lọc nhiễu FLUX (tạo ra các ô trống / dữ liệu khuyết `NaN`). Để đảm bảo mô hình 3D xuất ra là một khối kín hoàn chỉnh, ứng dụng Python `xyztostl.py` triển khai thuật toán nội suy tuyến tính lấp lỗ trống (`fill_missing`):

• Bán kính r(i, j) tại vị trí bị khuyết được tính toán bằng trung bình cộng bán kính của các điểm lân cận hợp lệ theo chiều góc quay và chiều đứng Z.
• Thuật toán giúp khôi phục liên tục bề mặt vật thể mà không làm thay đổi dạng hình học tổng thể.

2.6.3. Bộ lọc mượt bề mặt 3x3 (Smooth Filter)

Do cảm biến LiDAR TF-Luna có độ phân giải khoảng cách 1 cm, các dữ liệu đo thô có thể xuất hiện độ nhấp nhô nhỏ (nhiễu bước). Chương trình áp dụng bộ lọc mượt trung bình cửa sổ trượt 3×3 trên ma trận bán kính r(i, j):

r_smooth(i, j) = (1 / 9) · ∑_{di=-1}^{1} ∑_{dj=-1}^{1} r(i+di, j+dj)

Bộ lọc mượt giúp làm phẳng các gờ nhiễu bước nhỏ, tạo ra bề mặt mô hình 3D trơn mượt và tự nhiên.

2.6.4. Phương pháp dựng mặt tam giác và định dạng tệp STL nhị phân (Binary STL Format)

Tệp tin STL (Stereolithography) là chuẩn định dạng mô hình 3D phổ biến nhất trong công nghệ in 3D. Một mô hình STL biểu diễn bề mặt vật thể bằng tập hợp vô số các mặt tam giác phẳng nhỏ (Facets). Chương trình Python chuyển đổi ma trận lưới điểm đã làm mượt thành tệp STL nhị phân (Binary STL) qua 3 bước toán học:
1. Dựng mặt bên vật thể: Với mỗi ô lưới 4 điểm liền kề (P(i,j), P(i+1,j), P(i+1,j+1), P(i,j+1)), chia ô lưới thành 2 mặt tam giác phẳng.
2. Dựng mặt đáy và mặt đỉnh: Nối các điểm thuộc lớp đáy (j=0) về tâm đáy Z=0 và các điểm thuộc lớp đỉnh (j=M-1) về tâm đỉnh Z=Z_max để tạo khối kín hoàn toàn (Watertight Solid).
3. Tính toán véc-tơ pháp tuyến (Normal Vector): Với mỗi mặt tam giác có 3 đỉnh (V1, V2, V3), véc-tơ pháp tuyến đơn vị n được tính bằng tích có hướng (Cross Product) của hai véc-tơ cạnh:

n = (V2 - V1) × (V3 - V1) / ||(V2 - V1) × (V3 - V1)||

Tệp STL nhị phân được ghi theo cấu trúc chuẩn gồm 80 byte Header, 4 byte chứa số lượng mặt tam giác (Facet Count), và mỗi mặt tam giác chiếm 50 byte nhị phân (12 byte véc-tơ pháp tuyến + 36 byte tọa độ 3 đỉnh + 2 byte thuộc tính). Tệp STL thu được có dung lượng tối ưu, mở và cắt lớp cực nhanh trên phần mềm Cura hoặc PrusaSlicer.

Trường Đại học Sư phạm Kỹ thuật TP.HCM — Ngành Kỹ thuật Máy tính

Báo cáo Đồ án: Hệ thống Máy quét 3D Nhúng (ESP32-S3 & TF-Luna LiDAR)

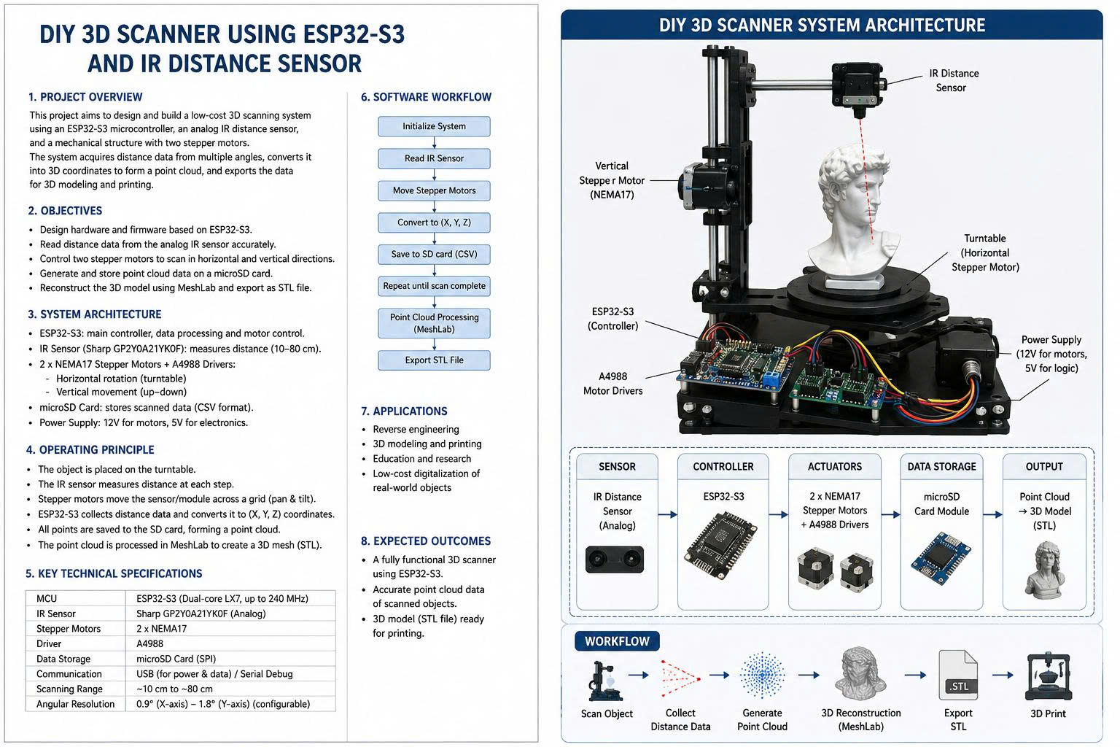
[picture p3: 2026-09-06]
Postter.jpg

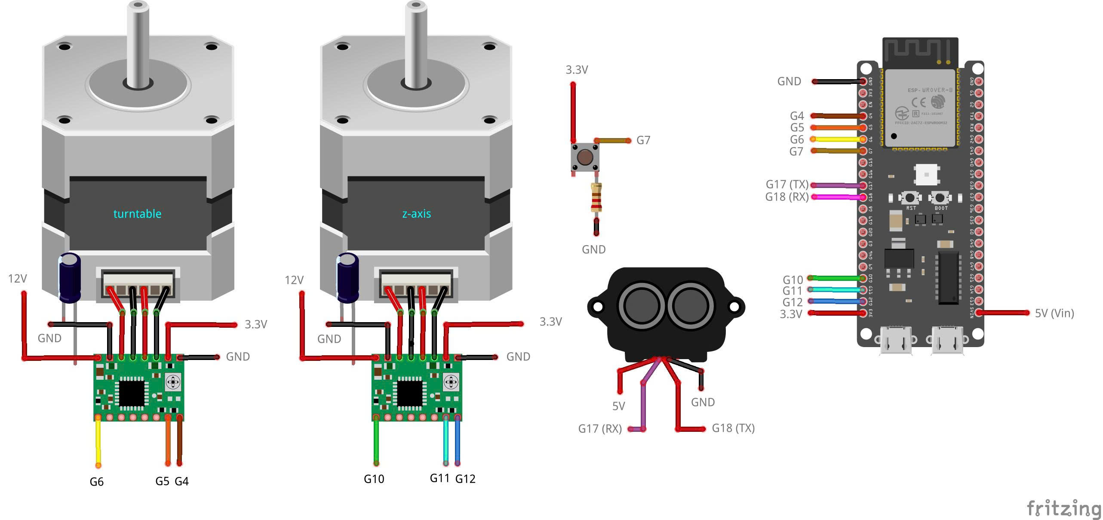
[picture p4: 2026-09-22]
Electrical_Circuit/Circuit_Diagram.jpg

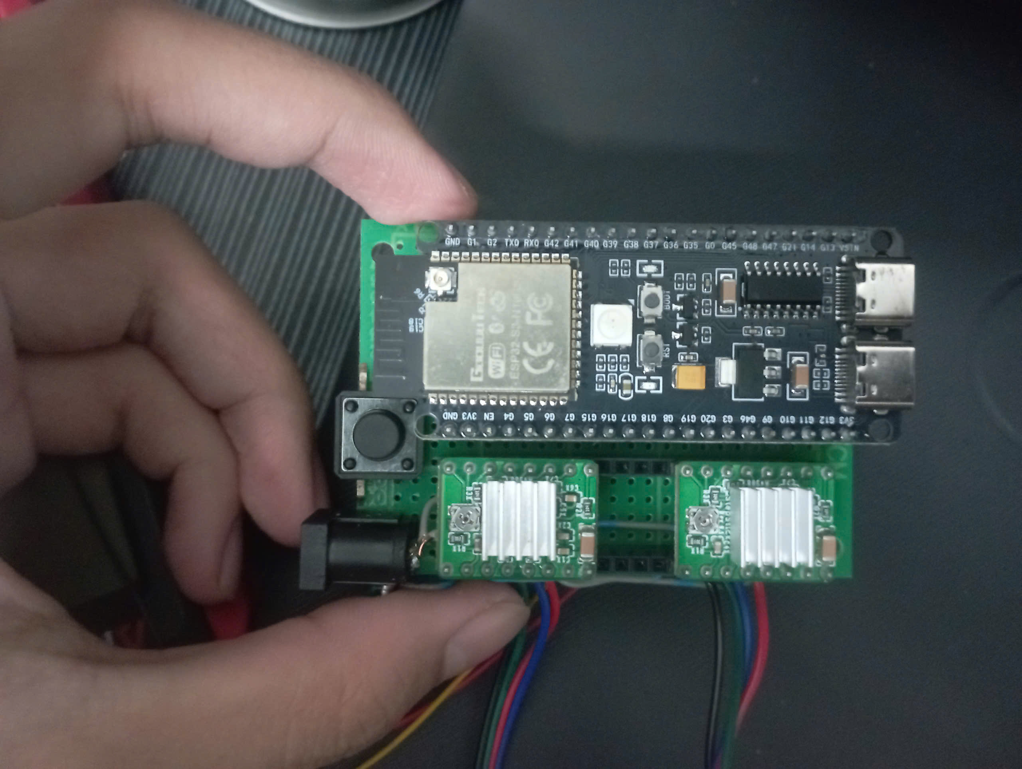
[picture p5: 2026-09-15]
Electrical_Circuit/pcb2o.jpg

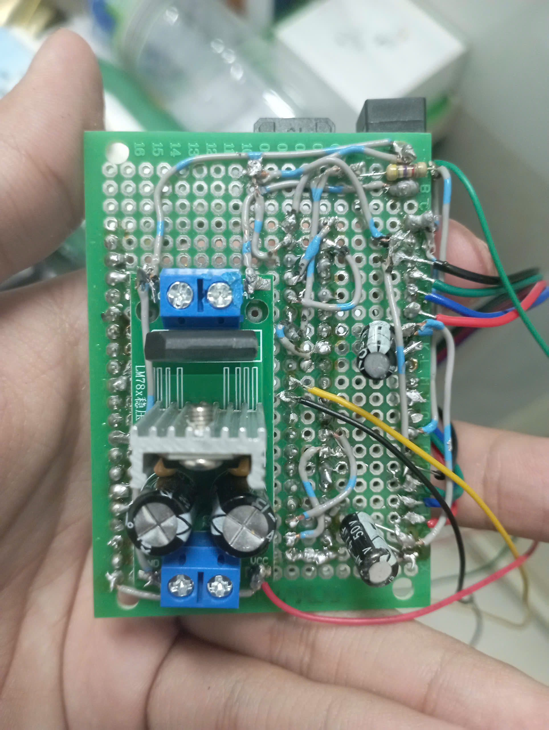
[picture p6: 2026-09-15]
Electrical_Circuit/pcb1.jpg

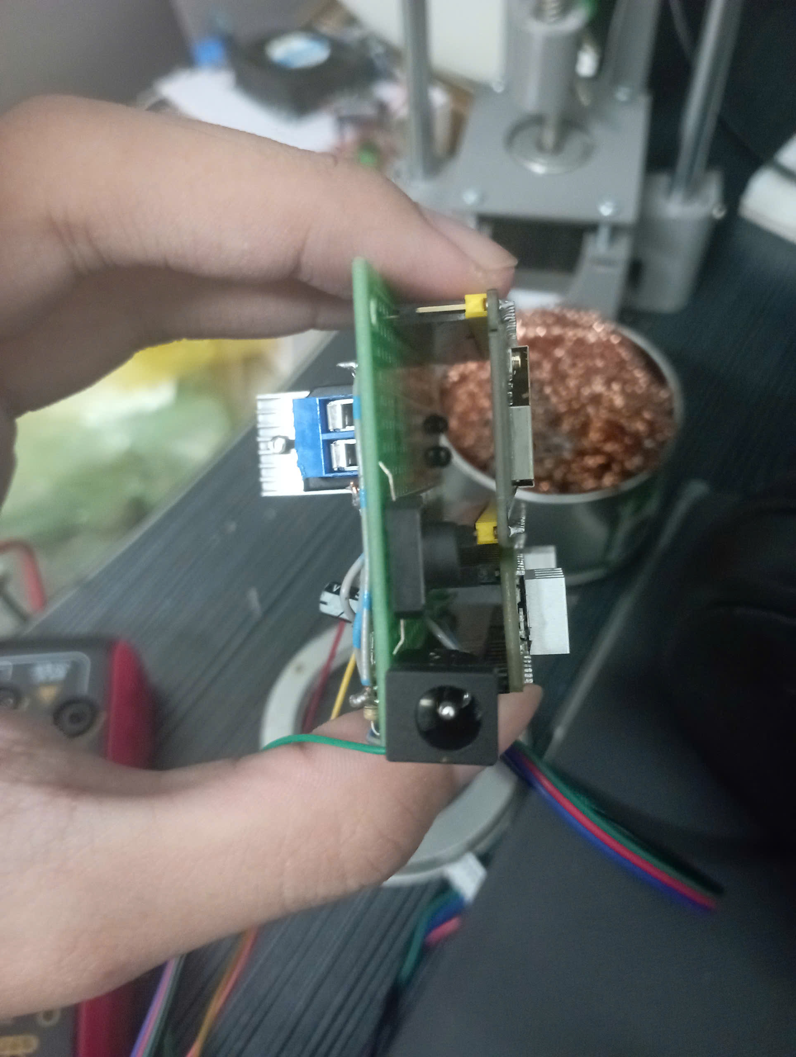
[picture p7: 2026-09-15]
Electrical_Circuit/pcb2u.jpg

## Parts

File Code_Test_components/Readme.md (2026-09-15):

# Component Test Code

This folder contains test programs for the main components of the ESP32-S3 3D Scanner project.

The code is used to verify each component before integrating it into the main system.

## Components Tested

* ESP32-S3 GPIO
* A4988 Turntable Motor
* A4988 Z-axis Motor
* TF-Luna Distance Sensor
* Z-axis HOME Button
* Status LED

## Tools

* Arduino IDE
* PlatformIDE
* VSCode IDE
* ESP32-S3 N16R8

## Test Purpose

Each program checks the basic operation, wiring, GPIO assignment, and communication of its corresponding component.

After all tests are completed successfully, the verified code will be integrated into the main scanner firmware.

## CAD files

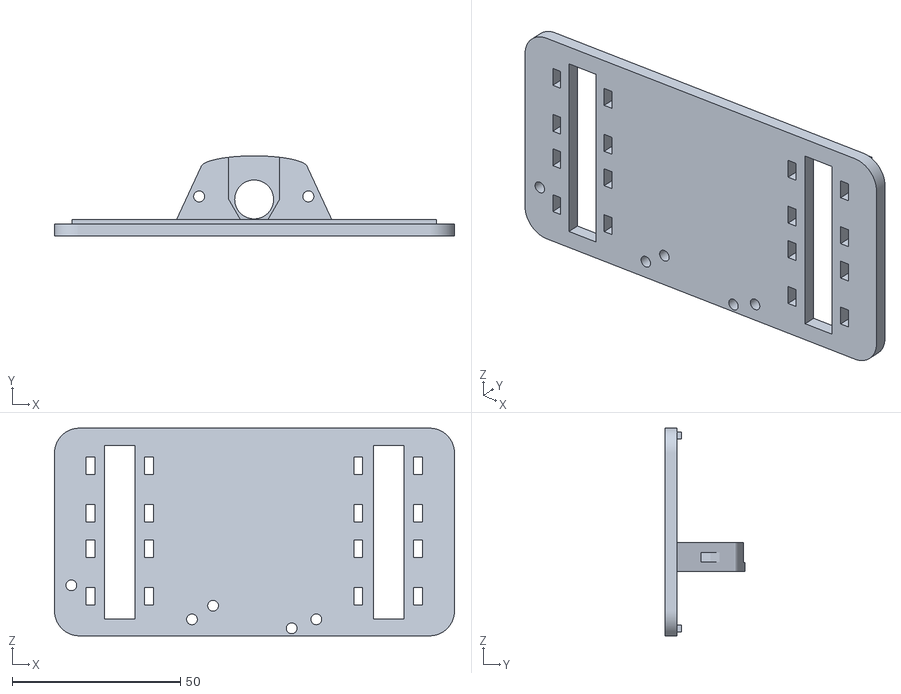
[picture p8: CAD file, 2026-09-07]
3D-printed frame/Carriage.stl
119.0 x 23.9 x 61.8

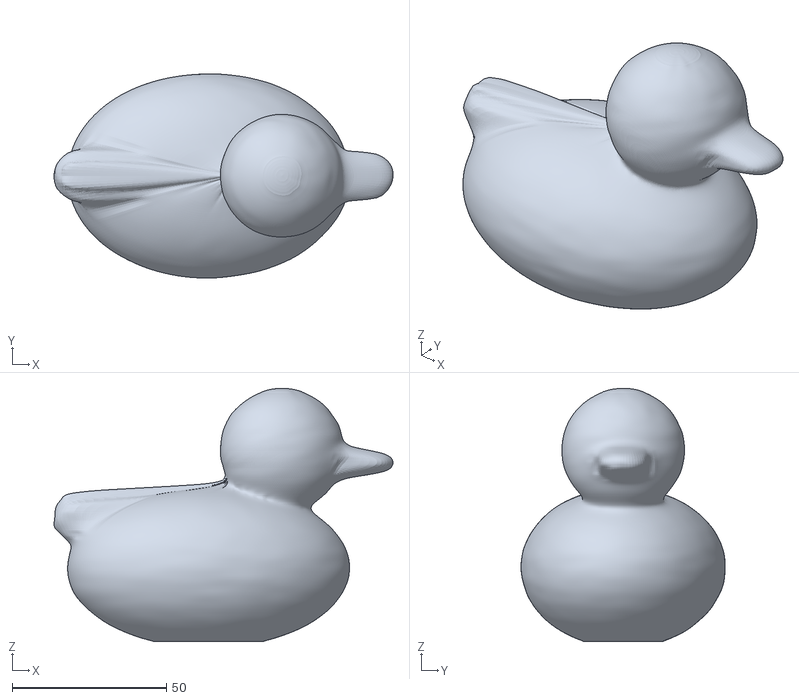
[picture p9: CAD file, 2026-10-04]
Maincode/test/scan_received.stl
109.7 x 66.1 x 82.1

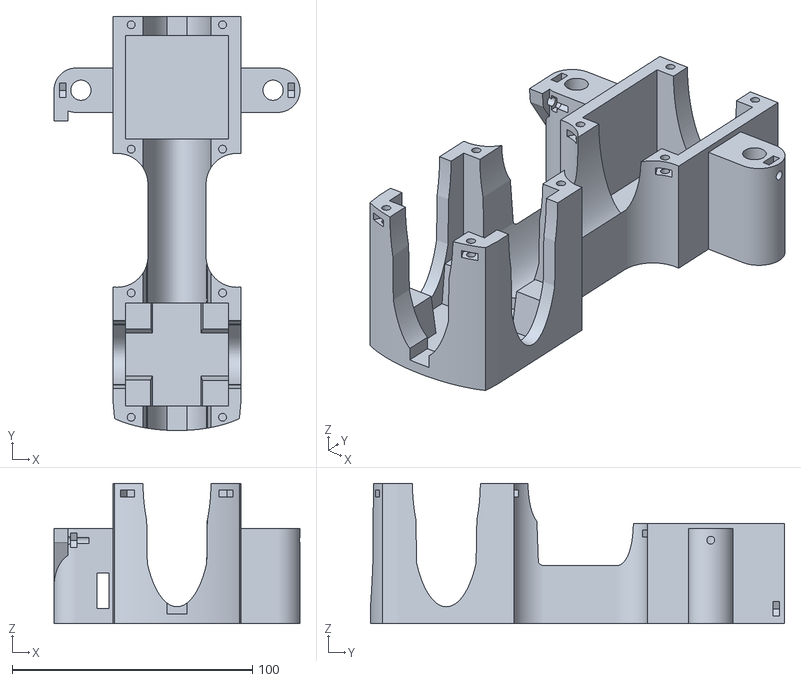
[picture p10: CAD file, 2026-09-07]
3D-printed frame/Base_body.stl
102.5 x 172.5 x 58.4

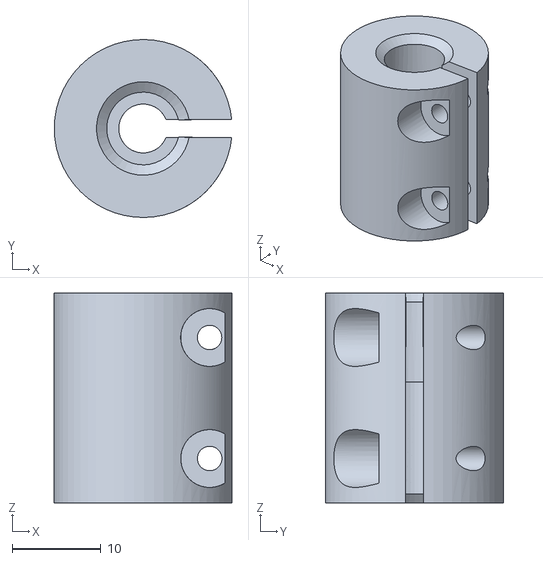
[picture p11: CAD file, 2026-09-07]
3D-printed frame/Coupler.stl
19.9 x 20.0 x 23.6

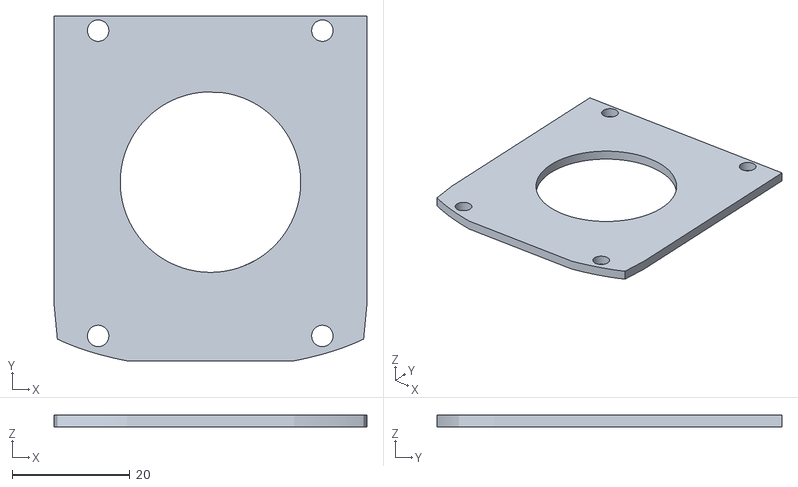
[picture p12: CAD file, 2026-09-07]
3D-printed frame/Front_motor_top.stl
53.1 x 58.5 x 2.00

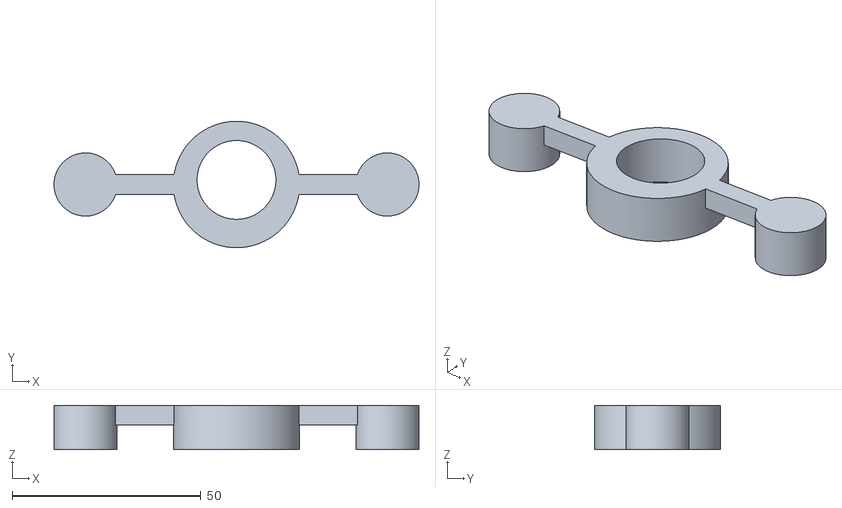
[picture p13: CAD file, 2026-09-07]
3D-printed frame/Top_z_axis.stl
96.8 x 33.5 x 11.7

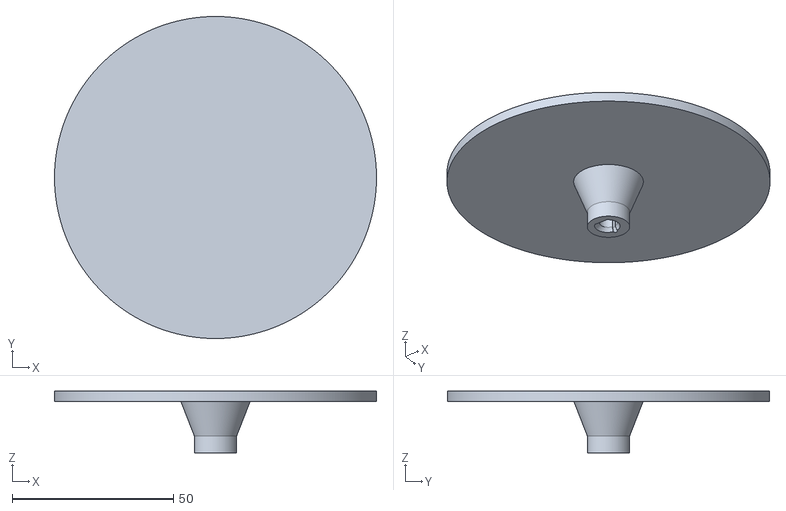
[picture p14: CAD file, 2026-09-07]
3D-printed frame/Turntable.stl
100.0 x 100.0 x 19.2

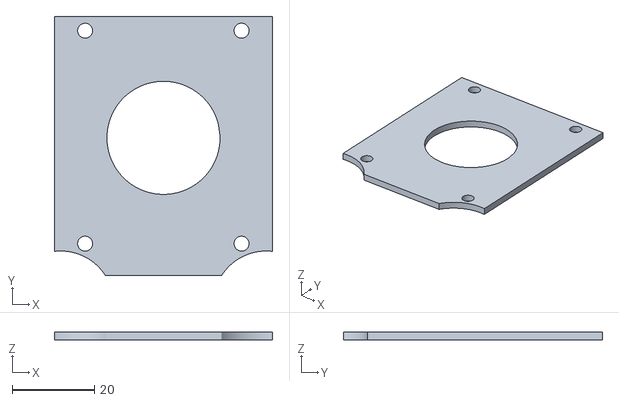
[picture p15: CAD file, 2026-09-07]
3D-printed frame/Rear_motor_top.stl
53.1 x 63.0 x 2.00

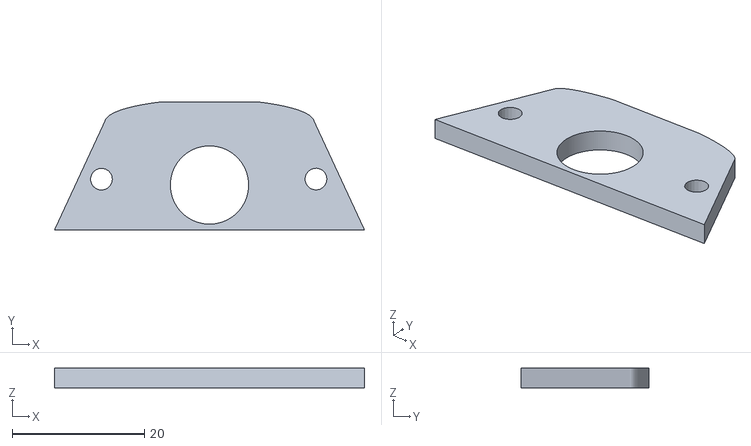
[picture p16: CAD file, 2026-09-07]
3D-printed frame/Z_carriage_nut_top.stl
46.9 x 19.3 x 3.00

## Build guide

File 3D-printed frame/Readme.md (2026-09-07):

# 3D-Printed Frame

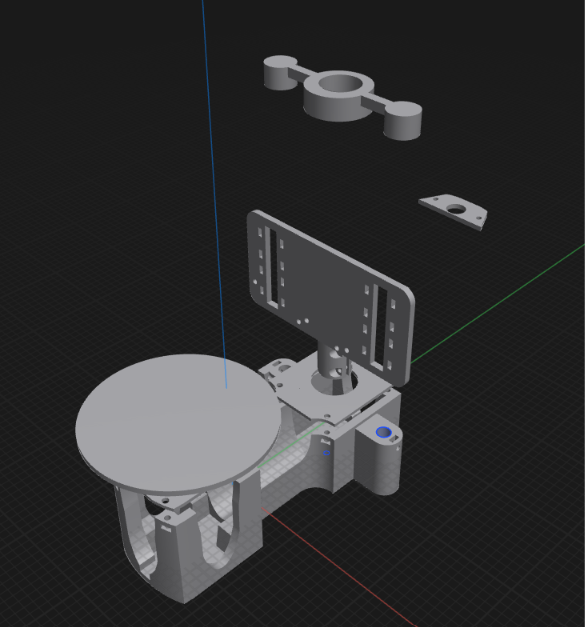
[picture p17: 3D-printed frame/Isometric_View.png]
Isometric View


This folder contains the **3D-printable mechanical frame and structural components** developed for the **ESP32-S3-Based 3D Scanning System**.

The mechanical frame is designed to provide a stable structure for the 3D scanner and support the installation of the main hardware components, such as the **ESP32-S3 development board, stepper motor, motor driver, scanning components, and other mechanical parts**.

The design process focuses on creating a compact, stable, and practical structure that can be easily manufactured using **3D printing technology**. The mechanical models were designed using **Shapr3D**, a CAD (**Computer-Aided Design**) tool used for creating and modifying 3D mechanical models.

## Contents

* **3D Models** – STL files prepared for 3D printing.
* **CAD Files** – Original mechanical design files created using Shapr3D.
* **Reference Images** – Images of the mechanical design and different views of the 3D scanner.

The mechanical frame is an important part of the system because it ensures proper component positioning and provides a stable platform for the 3D scanning process.

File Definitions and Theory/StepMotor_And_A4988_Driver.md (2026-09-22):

# Stepper Motor and A4988 Driver

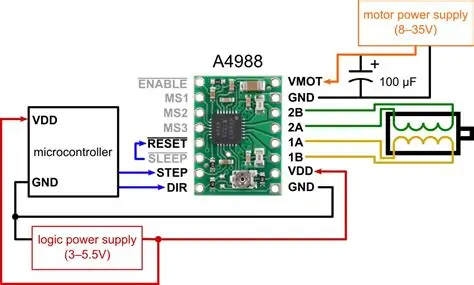
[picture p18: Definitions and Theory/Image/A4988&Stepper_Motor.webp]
A4988&Stepper_Motor


## Stepper Motor

A **Stepper Motor** is an electric motor that rotates in precise and discrete steps instead of continuous rotation. It is commonly used in applications that require accurate position and movement control.

### Key Features

* Precise position control
* Rotates in discrete steps
* High holding torque
* Suitable for CNC machines, 3D printers, and scanning systems
* Can be controlled accurately using step signals

## A4988 Stepper Motor Driver

The **A4988** is a stepper motor driver module designed to control bipolar stepper motors. It receives **STEP** and **DIR (Direction)** signals from a microcontroller and controls the movement and rotation direction of the motor.

### Key Features

* Motor supply voltage: **8 V – 35 V**
* Logic voltage: **3 V – 5.5 V**
* Supports microstepping up to **1/16 step**
* Adjustable current limiting
* Over-temperature protection

## Application in the 3D Scanner

In this **3D Scanner project**, the stepper motor is used to provide precise and controlled movement for the scanning mechanism. The A4988 driver allows the ESP32-S3 to control the motor using simple **STEP** and **DIR signals**.

This combination was selected because it provides **high positioning accuracy**, smooth movement, and easy integration with the ESP32-S3, making it suitable for rotating or moving an object during the 3D scanning process.

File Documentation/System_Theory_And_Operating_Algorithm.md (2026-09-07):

# System Theory and Operating Algorithm

## 1. Operating Theory

The proposed system is designed as a **3D object scanning system** that collects distance measurements from an object's surface at different positions.

The **ESP32-S3** acts as the main controller of the system. It controls the scanning process, communicates with the TF-Luna distance sensor, and generates control signals for the stepper motor driver.

The **Stepper Motor**, controlled through the **A4988 driver**, rotates the object or scanning platform by a predefined angle. The motor provides precise and repeatable movement, allowing measurements to be taken at multiple positions around the object.

At each scanning position, the **TF-Luna ToF (Time-of-Flight) LiDAR sensor** measures the distance between the sensor and the object's surface. The measured distance is transmitted digitally to the ESP32-S3.

By combining the **distance measurement** with the corresponding **rotation angle**, the system can collect multiple points representing the surface of the object.

After completing one scanning cycle, the collected measurement data can be used for further processing and **3D reconstruction**, such as generating a **point cloud** of the scanned object.

---

## 2. System Operating Algorithm

The system operates according to the following sequence:

1. Initialize the ESP32-S3 and configure all required GPIO and communication interfaces.
2. Initialize the TF-Luna distance sensor.
3. Initialize the A4988 driver and stepper motor.
4. Set the scanning mechanism to its initial position.
5. Rotate the object or scanning platform by a predefined angular step.
6. Stop or stabilize the motor at the current position.
7. Measure the distance between the TF-Luna sensor and the object.
8. Store the measured distance together with the corresponding scanning angle.
9. Repeat the rotation and measurement process until a complete scanning cycle is finished.
10. Collect all measurement data for further processing.
11. Generate or transmit the collected data for **3D point cloud reconstruction**.

---

## 3. System Data Flow

```text
Stepper Motor Movement
          ↓
    Object Position
          ↓
TF-Luna Distance Measurement
          ↓
       ESP32-S3
          ↓
Store Distance + Angle Data
          ↓
     Repeat Scanning
          ↓
   Complete Scan Cycle
          ↓
   Point Cloud Generation
          ↓
   3D Object Reconstruction
```

## 4. Scanning Principle

The basic scanning principle is based on collecting distance information at multiple angular positions.

For each position:

* The stepper motor determines the scanning angle.
* The TF-Luna measures the distance to the object.
* The ESP32-S3 stores the measurement data.

By repeating this process around the object, multiple surface points can be collected. These points can later be processed to represent the three-dimensional shape of the scanned object.

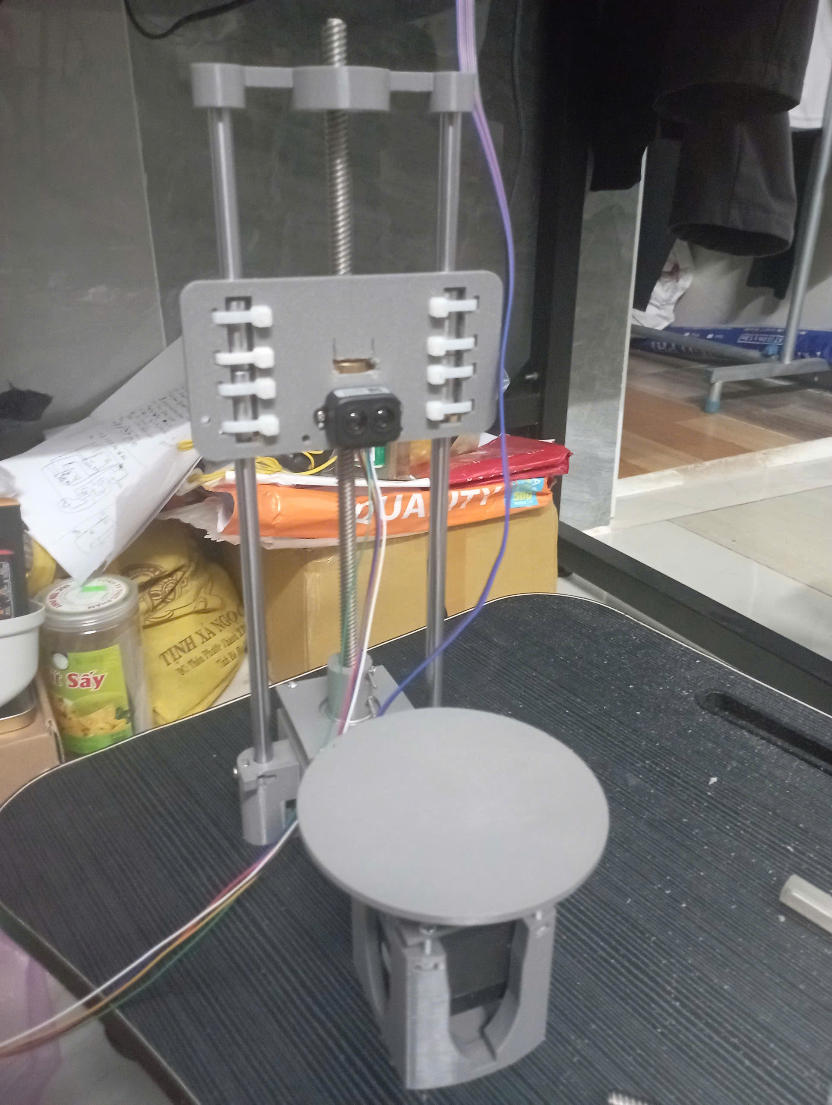
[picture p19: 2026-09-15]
3D-printed frame/khungscan.jpg

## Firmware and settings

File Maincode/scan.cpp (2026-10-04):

#include <Arduino.h>
#include <WiFi.h>
#include "freertos/FreeRTOS.h"
#include "freertos/task.h"
#include "freertos/queue.h"

const char* AP_SSID     = "ScannerESP32";
const char* AP_PASSWORD = "scanner123";
IPAddress serverIP(192, 168, 4, 2);
const uint16_t serverPort = 5000;
WiFiClient client;

const int PIN_TABLE_DIR  = 4;
const int PIN_TABLE_STEP = 5;
const int PIN_TABLE_EN   = 6;

const int PIN_Z_DIR  = 12;
const int PIN_Z_STEP = 11;
const int PIN_Z_EN   = 10;

const int PIN_TFLUNA_RX = 17;
const int PIN_TFLUNA_TX = 18;

const int PIN_HOME_BUTTON = 7;

HardwareSerial TFLunaSerial(1);
const uint32_t TFLUNA_BAUD = 115200;
const uint32_t TFLUNA_READ_TIMEOUT_MS = 50;

const int   TFLUNA_STRENGTH_FLOOR     = 100;
const int   TFLUNA_STRENGTH_SATURATED = 65535;
const bool  FILTER_EDGE_OUTLIERS      = true;
const float OUTLIER_DIST_MM           = 20.0;   // lech > 2 buoc do (TF-Luna 1 cm) so voi diem ke ben
const float OUTLIER_WEAK_RATIO        = 0.7;    // va strength < 70% strength cua cac diem ke ben
const int   OUTLIER_NEIGHBOURS        = 2;      // so diem ke ben moi phia dung de so sanh

struct ScanStats {
  long reads, readFail, weak, outOfRange, edgeRejected, kept;
};
ScanStats g_stats = {0, 0, 0, 0, 0, 0};

const int   MOTOR_STEPS_PER_REV = 200;
const int   MICROSTEPPING       = 16;
const int   TOTAL_STEPS_PER_REV = MOTOR_STEPS_PER_REV * MICROSTEPPING;
const float LEAD_SCREW_PITCH_MM = 8.0;

const int   STEPS_PER_REV    = 80;
const float D_ANGLE          = 2.0 * PI / STEPS_PER_REV;
const int   STEPS_PER_SAMPLE = TOTAL_STEPS_PER_REV / STEPS_PER_REV;

const float Z_LAYER_MM = 1.0;

const float Z_TRAVEL_LIMIT_MM = 150.0; // gioi han truc Z

const int   Z_STEPS_PER_LAYER = (int)((Z_LAYER_MM / LEAD_SCREW_PITCH_MM) * TOTAL_STEPS_PER_REV);

const float Z_MIN_SCAN_MM        = 10.0;
const int   EMPTY_LAYERS_TO_STOP = 2;

const bool RETURN_Z_AFTER_SCAN = true;

const float DISTANCE_TO_CENTER_CM = 28.0;
const float MAX_RADIUS_MM         = 150.0;

const int STEP_DELAY_US = 600;

const int TABLE_DIR_LEVEL = HIGH;
const int Z_UP_LEVEL      = HIGH;

const int YIELD_EVERY_STEPS = 200;

const BaseType_t CORE_REALTIME = 1;
const BaseType_t CORE_COMM     = 0;

const uint32_t BUTTON_DEBOUNCE_MS = 30;
const uint32_t BUTTON_LONG_MS     = 2000;

const bool DISABLE_DRIVERS_ON_FAULT = false;

long  mmToSteps(float mm)   { return (long)(mm / LEAD_SCREW_PITCH_MM * TOTAL_STEPS_PER_REV + 0.5f); }
float stepsToMm(long steps) { return steps * LEAD_SCREW_PITCH_MM / TOTAL_STEPS_PER_REV; }

const long Z_MAX_STEPS = mmToSteps(Z_TRAVEL_LIMIT_MM);

enum FaultCode {
  FAULT_NONE = 0,
  FAULT_SOFT_MAX,      // lenh muon dua Z vuot Z_TRAVEL_LIMIT_MM
  FAULT_USER_STOP      // nhan nut HOME / go "stop" khi dang chay
};

volatile FaultCode g_fault          = FAULT_NONE;
volatile bool      g_abortRequested = false;   // core 0 bat, core 1 doc moi xung
volatile long      g_zPosSteps      = 0;       // vi tri Z hien tai (xung), 0 = day
volatile bool      g_zHomed         = false;   // true khi da co z=0
volatile bool      g_busy           = false;   // motorTask dang chay lenh

const char* faultName(FaultCode f) {
  switch (f) {
    case FAULT_NONE:      return "KHONG LOI";
    case FAULT_SOFT_MAX:  return "VUOT GIOI HAN TRUC Z (Z_TRAVEL_LIMIT_MM)";
    case FAULT_USER_STOP: return "DA DUNG (nut HOME / lenh stop)";
  }
  return "?";
}

enum CmdType { CMD_START, CMD_UP, CMD_DOWN, CMD_ZERO, CMD_CLEAR, CMD_OFF };
struct MotorCmd {
  CmdType type;
  float   arg;
};
QueueHandle_t cmdQueue = NULL;

struct RawSample {
  float radiusMm;
  float angleRad;
  float zMm;
  bool  endOfScan;
  bool  aborted;     // true = quet bi dung giua chung
};
const int QUEUE_LENGTH = 256;
QueueHandle_t rawQueue = NULL;

void connectToServer() {
  Serial.println("Waiting for PC server...");
  while (!client.connect(serverIP, serverPort)) {
    Serial.println("  connect failed, retrying in 1s...");
    delay(1000);
  }
  Serial.println("Connected to PC.");
}

void tfLunaInit() {
  TFLunaSerial.begin(TFLUNA_BAUD, SERIAL_8N1, PIN_TFLUNA_RX, PIN_TFLUNA_TX);
  delay(100);
}

bool readTFLunaRaw(int& distanceCm, int& strength) {

  while (TFLunaSerial.available()) TFLunaSerial.read();

  uint8_t buf[9];
  int idx = 0;
  uint32_t t0 = millis();
  while (millis() - t0 < TFLUNA_READ_TIMEOUT_MS) {
    if (!TFLunaSerial.available()) {
      delay(1);
      continue;
    }
    uint8_t b = TFLunaSerial.read();

    if (idx < 2) {
      if (b == 0x59) buf[idx++] = b;
      else idx = 0;
    } else {
      buf[idx++] = b;
      if (idx == 9) {
        uint8_t sum = 0;
        for (int i = 0; i < 8; i++) sum += buf[i];
        if (sum != buf[8]) { idx = 0; continue; }

        distanceCm = buf[2] | (buf[3] << 8);
        strength   = buf[4] | (buf[5] << 8);
        return true;
      }
    }
  }
  return false;
}

static bool g_driversOn = false;

void enableDrivers() {
  digitalWrite(PIN_TABLE_EN, LOW);
  digitalWrite(PIN_Z_EN, LOW);
  if (!g_driversOn) {
    g_driversOn = true;
    delay(5);
  }
}

void disableDrivers() {
  digitalWrite(PIN_TABLE_EN, HIGH);
  digitalWrite(PIN_Z_EN, HIGH);
  g_driversOn = false;
}

void raiseFault(FaultCode code, const char* detail) {
  if (g_fault == FAULT_NONE) g_fault = code;   // giu lai loi DAU TIEN
  Serial.println();
  Serial.printf("!!! %s  (%s)  z=%.2f mm\n", faultName(code), detail, stepsToMm(g_zPosSteps));
  Serial.println("!!! May dung yen tai cho. Nhan HOME de quet lai, giu HOME 2s de nha motor.");
  if (DISABLE_DRIVERS_ON_FAULT) disableDrivers();
}

void stepPulse(int stepPin) {
  digitalWrite(stepPin, HIGH);
  delayMicroseconds(5);
  digitalWrite(stepPin, LOW);
  delayMicroseconds(STEP_DELAY_US);
}

bool rotateTableSteps(long steps) {
  enableDrivers();
  digitalWrite(PIN_TABLE_DIR, TABLE_DIR_LEVEL);
  delayMicroseconds(5);   // A4988: DIR on dinh truoc canh len STEP
  for (long i = 0; i < steps; i++) {
    if (g_abortRequested) {
      raiseFault(FAULT_USER_STOP, "khi dang quay ban xoay");
      return false;
    }
    stepPulse(PIN_TABLE_STEP);
    if ((i + 1) % YIELD_EVERY_STEPS == 0) delay(1);
  }
  return true;
}

bool moveZSteps(long steps, bool up) {
  if (steps <= 0) return true;
  enableDrivers();
  const int downLevel = (Z_UP_LEVEL == HIGH) ? LOW : HIGH;
  digitalWrite(PIN_Z_DIR, up ? Z_UP_LEVEL : downLevel);
  delayMicroseconds(5);   // A4988: DIR on dinh truoc canh len STEP

  for (long i = 0; i < steps; i++) {
    if (g_abortRequested) {
      raiseFault(FAULT_USER_STOP, "khi dang chay truc Z");
      return false;
    }
    if (g_zHomed) {
      if (up && g_zPosSteps >= Z_MAX_STEPS) {
        raiseFault(FAULT_SOFT_MAX, "lenh muon di qua dinh truc");
        return false;
      }
      if (!up && g_zPosSteps <= 0) {
        Serial.println("[z] Da o z=0 (day truc), khong ha them.");
        return true;
      }
    }
    stepPulse(PIN_Z_STEP);
    g_zPosSteps = g_zPosSteps + (up ? 1 : -1);
    if ((i + 1) % YIELD_EVERY_STEPS == 0) delay(1);
  }
  return true;
}

bool moveZToSteps(long target) {
  long delta = target - g_zPosSteps;
  if (delta > 0) return moveZSteps(delta, true);
  if (delta < 0) return moveZSteps(-delta, false);
  return true;
}

bool stepTurntable() { return rotateTableSteps(STEPS_PER_SAMPLE); }
bool stepZAxis()     { return moveZSteps(Z_STEPS_PER_LAYER, true); }

void printStatus() {
  Serial.println("----- TRANG THAI -----");
  Serial.printf("Trang thai: %s\n", g_busy ? "DANG CHAY" : "dung yen");
  Serial.printf("Loi       : %s\n", faultName(g_fault));
  Serial.printf("Vi tri Z  : %.2f mm (%ld xung)  %s\n", stepsToMm(g_zPosSteps), (long)g_zPosSteps,
                g_zHomed ? "[da co z=0]" : "[CHUA co z=0 - nhan HOME khi Z o thap nhat]");
  Serial.printf("Gioi han  : 0 .. %.1f mm\n", Z_TRAVEL_LIMIT_MM);
  Serial.printf("Loc diem  : strength >= %d, bo lan mep %s (lech > %.0f mm va yeu < %.0f%%)\n",
                TFLUNA_STRENGTH_FLOOR, FILTER_EDGE_OUTLIERS ? "BAT" : "TAT", OUTLIER_DIST_MM, OUTLIER_WEAK_RATIO * 100);
  Serial.printf("Lan quet cuoi: giu %ld / %ld lan doc, bo lan mep %ld\n", g_stats.kept, g_stats.reads, g_stats.edgeRejected);
  Serial.println("----------------------");
}

void printHelp() {
  Serial.println("----- NUT HOME -----");
  Serial.println("  Nhan khi dung yen : bat dau quet");
  Serial.println("  Nhan khi dang chay: DUNG ngay, dung yen tai cho");
  Serial.println("  Giu 2 giay        : nha motor de chinh tay truc Z");
  Serial.println("----- LENH Serial Monitor (115200, Enter) -----");
  Serial.println("  stop       dung ngay (giong nhan HOME khi dang chay)");
  Serial.println("  scan       bat dau quet (giong nhan HOME khi dung yen)");
  Serial.println("  status     xem trang thai");
  Serial.println("  clear      xoa thong bao loi");
  Serial.println("  up <mm>    nang Z <mm>  (van bi gioi han mem chan)");
  Serial.println("  down <mm>  ha Z <mm>");
  Serial.println("  zero       coi vi tri hien tai la z=0");
  Serial.println("  off        nha motor (giong giu HOME 2 giay)");
  Serial.println("  help       in danh sach nay");
  Serial.println("-----------------------------------------------");
}

static float    layerR[STEPS_PER_REV];   // ban kinh (mm) tung goc trong lop, < 0 = khong hop le
static uint16_t layerS[STEPS_PER_REV];   // strength tung goc

static float median4(float* v, int n) {   // n <= 2*OUTLIER_NEIGHBOURS
  for (int i = 1; i < n; i++) {
    float x = v[i]; int j = i - 1;
    while (j >= 0 && v[j] > x) { v[j + 1] = v[j]; j--; }
    v[j + 1] = x;
  }
  return (n % 2) ? v[n / 2] : 0.5f * (v[n / 2 - 1] + v[n / 2]);
}

float readSample(uint16_t& strengthOut) {
  int dist, strength;
  g_stats.reads++;
  strengthOut = 0;
  if (!readTFLunaRaw(dist, strength)) { g_stats.readFail++; return -1; }
  strengthOut = (uint16_t)strength;
  if (strength < TFLUNA_STRENGTH_FLOOR || strength >= TFLUNA_STRENGTH_SATURATED) { g_stats.weak++; return -1; }
  float rMm = (DISTANCE_TO_CENTER_CM - dist) * 10.0f;
  if (rMm <= 0 || rMm > MAX_RADIUS_MM) { g_stats.outOfRange++; return -1; }
  return rMm;
}

int rejectEdgeOutliers() {
  if (!FILTER_EDGE_OUTLIERS) return 0;
  static bool reject[STEPS_PER_REV];
  int count = 0;
  for (int i = 0; i < STEPS_PER_REV; i++) {
    reject[i] = false;
    if (layerR[i] < 0) continue;
    float nr[2 * OUTLIER_NEIGHBOURS], ns[2 * OUTLIER_NEIGHBOURS];
    int n = 0;
    for (int d = -OUTLIER_NEIGHBOURS; d <= OUTLIER_NEIGHBOURS; d++) {
      if (d == 0) continue;
      int j = (i + d + STEPS_PER_REV) % STEPS_PER_REV;
      if (layerR[j] < 0) continue;
      nr[n] = layerR[j];
      ns[n] = layerS[j];
      n++;
    }
    if (n < 2) continue;                                 // khong du diem ke ben de danh gia -> giu
    float rMed = median4(nr, n), sMed = median4(ns, n);
    if (fabsf(layerR[i] - rMed) > OUTLIER_DIST_MM && layerS[i] < OUTLIER_WEAK_RATIO * sMed) {
      reject[i] = true;
      count++;
    }
  }
  for (int i = 0; i < STEPS_PER_REV; i++) if (reject[i]) layerR[i] = -1;
  return count;
}

bool runScan() {
  Serial.println("[core1] Bat dau quet toa do tu z=0 (khong can vong hieu chinh rieng).");
  uint32_t startMs = millis();
  int  emptyLayers = 0;
  bool aborted     = false;
  g_stats = {0, 0, 0, 0, 0, 0};

  for (int layer = 0; !aborted; layer++) {
    float z = layer * Z_LAYER_MM;

    for (int i = 0; i < STEPS_PER_REV; i++) {
      layerR[i] = readSample(layerS[i]);
      if (!stepTurntable()) { aborted = true; break; }
    }
    if (aborted) break;

    int rejected = rejectEdgeOutliers();
    g_stats.edgeRejected += rejected;
    int validThisLayer = 0;
    for (int i = 0; i < STEPS_PER_REV; i++) {
      if (layerR[i] < 0) continue;
      validThisLayer++;
      RawSample s = { layerR[i], i * D_ANGLE, z, false, false };
      xQueueSend(rawQueue, &s, pdMS_TO_TICKS(5000));
    }
    g_stats.kept += validThisLayer;

    if (z >= Z_MIN_SCAN_MM) {
      if (validThisLayer == 0) {
        if (++emptyLayers >= EMPTY_LAYERS_TO_STOP) {
          Serial.printf("[core1] Top of object reached at z=%.0fmm. Stopping.\n", z);
          break;
        }
      } else {
        emptyLayers = 0;
      }
    }

    if ((layer + 1) * Z_LAYER_MM > Z_TRAVEL_LIMIT_MM) {
      Serial.printf("[core1] Reached travel limit (%.0fmm). Stopping.\n", Z_TRAVEL_LIMIT_MM);
      break;
    }

    if (!stepZAxis()) { aborted = true; break; }

    if ((layer + 1) % 10 == 0) {
      Serial.printf("[core1] layer %d done (z=%.0fmm), %lu s elapsed, lop nay: %d diem, bo %d diem lan mep\n",
                    layer + 1, z, (millis() - startMs) / 1000, validThisLayer, rejected);
    }
  }
  Serial.printf("[core1] Doc %ld lan: giu %ld, loi khung %ld, yeu/bao hoa %ld, ngoai vung %ld, lan mep %ld\n",
                g_stats.reads, g_stats.kept, g_stats.readFail, g_stats.weak, g_stats.outOfRange, g_stats.edgeRejected);
  Serial.printf("[core1] Thoi gian quet: %lu s\n", (millis() - startMs) / 1000);

  RawSample endMarker = { 0, 0, 0, true, aborted };
  xQueueSend(rawQueue, &endMarker, pdMS_TO_TICKS(2000));

  if (aborted) {
    Serial.println("[core1] Quet bi DUNG. May dung yen tai cho, cho lenh tiep theo.");
    return false;
  }

  Serial.println("[core1] Motion complete.");
  if (RETURN_Z_AFTER_SCAN && g_zPosSteps > 0) {
    Serial.printf("[core1] Dang ha truc Z ve z=0 (dang o %.1f mm)...\n", stepsToMm(g_zPosSteps));
    if (!moveZToSteps(0)) return false;
    Serial.println("[core1] Da ve z=0. Nhan HOME de quet lan tiep theo.");
  }
  disableDrivers();
  return true;
}

void startScan() {
  if (g_fault != FAULT_NONE) {
    Serial.printf("Xoa trang thai '%s'.\n", faultName(g_fault));
    g_fault = FAULT_NONE;
  }
  enableDrivers();

  if (!g_zHomed) {
    g_zPosSteps = 0;
    g_zHomed    = true;
    Serial.println("Lay vi tri hien tai lam z=0 (truc Z phai dang o THAP NHAT).");
  } else if (g_zPosSteps != 0) {
    Serial.printf("Dua Z ve z=0 truoc khi quet (dang o %.1f mm)...\n", stepsToMm(g_zPosSteps));
    if (!moveZToSteps(0)) return;
  }

  runScan();
}

void handleCommand(const MotorCmd& c) {
  switch (c.type) {
    case CMD_START:
      startScan();
      return;

    case CMD_UP:
    case CMD_DOWN: {
      float mm = c.arg;
      if (mm <= 0) { Serial.println("Can so mm > 0, vd: up 5"); return; }
      if (mm > Z_TRAVEL_LIMIT_MM) mm = Z_TRAVEL_LIMIT_MM;
      if (!g_zHomed) Serial.println("[z] Chu y: chua co z=0 -> gioi han mem dang TAT, chi di dung so mm da go.");
      bool up = (c.type == CMD_UP);
      Serial.printf("[z] %s %.2f mm...\n", up ? "Nang" : "Ha", mm);
      if (moveZSteps(mmToSteps(mm), up))
        Serial.printf("[z] Xong. z=%.2f mm\n", stepsToMm(g_zPosSteps));
      return;
    }

    case CMD_ZERO:
      g_zPosSteps = 0;
      g_zHomed    = true;
      Serial.println("Da dat vi tri hien tai la z=0.");
      return;

    case CMD_CLEAR:
      g_fault = FAULT_NONE;
      Serial.println("Da xoa thong bao loi.");
      printStatus();
      return;

    case CMD_OFF:
      disableDrivers();
      g_zHomed = false;
      Serial.println("Da NHA motor. Chinh truc Z bang tay xuong THAP NHAT, roi nhan HOME de quet (vi tri do = z=0).");
      return;
  }
}

void motorTask(void* pv) {
  Serial.println("Dat vat len GIUA ban xoay, ha truc Z xuong THAP NHAT (ngang mat ban xoay),");
  Serial.println("roi nhan nut HOME (GPIO7). May quet ngay tu z=0 (loc diem theo tung lop, khong can quet thu).");
  printHelp();

  for (;;) {
    MotorCmd cmd;
    if (xQueueReceive(cmdQueue, &cmd, portMAX_DELAY) != pdTRUE) continue;
    g_abortRequested = false;   // lenh dung cu khong anh huong lenh moi
    g_busy = true;
    handleCommand(cmd);
    g_busy = false;
  }
}

void queueCmd(CmdType t, float arg = 0) {
  MotorCmd c;
  c.type = t;
  c.arg  = arg;
  if (g_busy) Serial.println(">> May dang chay, lenh se chay sau khi xong (nhan HOME / go 'stop' de dung ngay).");
  if (xQueueSend(cmdQueue, &c, 0) != pdTRUE) Serial.println(">> Hang doi lenh day, bo qua.");
}

void pollHomeButton() {
  static int      lastRaw  = HIGH;
  static int      stable   = HIGH;
  static uint32_t tChange  = 0;
  static uint32_t tPress   = 0;
  static bool     consumed = false;

  int raw = digitalRead(PIN_HOME_BUTTON);
  uint32_t now = millis();
  if (raw != lastRaw) { lastRaw = raw; tChange = now; }

  if (raw != stable && now - tChange >= BUTTON_DEBOUNCE_MS) {
    stable = raw;
    if (stable == LOW) {                       // vua nhan xuong
      tPress   = now;
      consumed = false;
      if (g_busy) {
        g_abortRequested = true;
        consumed = true;
        Serial.println(">> Nut HOME: DUNG MAY");
      }
    } else if (!consumed) {                    // nha ra sau lan nhan ngan
      Serial.println(">> Nut HOME: BAT DAU QUET");
      queueCmd(CMD_START);
    }
  }

  if (stable == LOW && !consumed && now - tPress >= BUTTON_LONG_MS) {
    consumed = true;
    Serial.println(">> Giu nut HOME 2s: NHA MOTOR");
    queueCmd(CMD_OFF);
  }
}

void processLine(char* line) {
  for (char* p = line; *p; p++) *p = tolower(*p);
  char word[16] = {0};
  float arg = 0;
  int n = sscanf(line, "%15s %f", word, &arg);
  if (n < 1) return;

  if (!strcmp(word, "stop") || !strcmp(word, "s")) {
    g_abortRequested = true;
    Serial.println(g_busy ? ">> STOP: dang dung may..." : ">> May dang dung yen.");
    return;
  }
  if (!strcmp(word, "status")) { printStatus(); return; }
  if (!strcmp(word, "help") || !strcmp(word, "?")) { printHelp(); return; }

  if      (!strcmp(word, "scan"))  queueCmd(CMD_START);
  else if (!strcmp(word, "up"))    queueCmd(CMD_UP, arg);
  else if (!strcmp(word, "down"))  queueCmd(CMD_DOWN, arg);
  else if (!strcmp(word, "zero"))  queueCmd(CMD_ZERO);
  else if (!strcmp(word, "clear")) queueCmd(CMD_CLEAR);
  else if (!strcmp(word, "off"))   queueCmd(CMD_OFF);
  else Serial.printf("Lenh khong hop le: '%s'. Go 'help'.\n", word);
}

void cmdTask(void* pv) {
  char line[48];
  size_t len = 0;
  for (;;) {
    pollHomeButton();
    while (Serial.available()) {
      char ch = (char)Serial.read();
      if (ch == '\r' || ch == '\n') {
        if (len > 0) {
          line[len] = 0;
          processLine(line);
          len = 0;
        }
      } else if (len < sizeof(line) - 1) {
        line[len++] = ch;
      }
    }
    vTaskDelay(pdMS_TO_TICKS(10));
  }
}

static char   txBuf[1460];
static size_t txLen = 0;

void flushTxBuffer() {
  if (txLen == 0) return;
  if (!client.connected()) {
    Serial.println("[core0] Connection lost, reconnecting...");
    connectToServer();
  }
  client.write((const uint8_t*)txBuf, txLen);
  txLen = 0;
}

void commTask(void* pv) {
  RawSample s;
  for (;;) {
    if (xQueueReceive(rawQueue, &s, portMAX_DELAY) != pdTRUE) continue;

    if (s.endOfScan) {
      flushTxBuffer();
      client.stop();
      Serial.println();
      if (s.aborted) {
        Serial.println("=============== SCAN STOPPED ===============");
        Serial.println("Quet bi dung giua chung. File tren PC chi co mot phan diem.");
      } else {
        Serial.println("=============== SCAN COMPLETE ===============");
        Serial.println("File complete on PC. Run xyz_to_stl.py to build the STL.");
      }
      Serial.println("Chay lai pcrecieve.py truoc lan quet tiep theo.");
      Serial.println("=============================================");
      continue;   // khong xoa task -> quet duoc nhieu lan
    }

    float x = s.radiusMm * cos(s.angleRad);
    float y = s.radiusMm * sin(s.angleRad);

    if (sizeof(txBuf) - txLen < 40) flushTxBuffer();
    int n = snprintf(txBuf + txLen, sizeof(txBuf) - txLen, "%.2f,%.2f,%.2f\n", x, y, s.zMm);
    if (n > 0) txLen += n;
  }
}

void setup() {
  Serial.begin(115200);
  delay(500);

  pinMode(PIN_TABLE_STEP, OUTPUT);
  pinMode(PIN_TABLE_DIR,  OUTPUT);
  pinMode(PIN_TABLE_EN,   OUTPUT);
  pinMode(PIN_Z_STEP,     OUTPUT);
  pinMode(PIN_Z_DIR,      OUTPUT);
  pinMode(PIN_Z_EN,       OUTPUT);
  enableDrivers();
  pinMode(PIN_HOME_BUTTON, INPUT_PULLUP);

  tfLunaInit();
  int d0, s0;
  if (readTFLunaRaw(d0, s0)) {
    Serial.printf("TF-Luna OK: dist=%d cm, strength=%d\n", d0, s0);
  } else {
    Serial.println("WARNING: chua nhan duoc khung hop le tu TF-Luna. Kiem tra day TXD/RXD, nguon cap.");
  }

  WiFi.softAP(AP_SSID, AP_PASSWORD);
  Serial.print("AP started. ESP32-S3 IP: ");
  Serial.println(WiFi.softAPIP());
  Serial.println("Connect laptop to 'ScannerESP32', start pc_receiver.py.");
  delay(5000);
  connectToServer();

  rawQueue = xQueueCreate(QUEUE_LENGTH, sizeof(RawSample));
  cmdQueue = xQueueCreate(8, sizeof(MotorCmd));
  if (rawQueue == NULL || cmdQueue == NULL) {
    Serial.println("ERROR: cannot create queue.");
    while (true) delay(1000);
  }

  xTaskCreatePinnedToCore(commTask,  "comm",  8192, NULL, 1, NULL, CORE_COMM);
  xTaskCreatePinnedToCore(cmdTask,   "cmd",   4096, NULL, 2, NULL, CORE_COMM);
  xTaskCreatePinnedToCore(motorTask, "motor", 6144, NULL, 3, NULL, CORE_REALTIME);

  Serial.println("Dual-core pipeline started.");
}

void loop() {
  delay(1000);
}

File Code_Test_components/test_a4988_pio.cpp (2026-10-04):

#include <Arduino.h>

const int PIN_TABLE_DIR  = 4;
const int PIN_TABLE_STEP = 5;
const int PIN_TABLE_EN   = 6;

const int PIN_Z_DIR  = 12;
const int PIN_Z_STEP = 11;
const int PIN_Z_EN   = 10;

const int MOTOR_STEPS_PER_REV = 200;   // NEMA17 1,8 do/buoc
const int MICROSTEPPING       = 16;    // TODO: khop voi jumper MS1/MS2/MS3 that tren A4988
const int TOTAL_STEPS_PER_REV = MOTOR_STEPS_PER_REV * MICROSTEPPING;
const int STEP_DELAY_US       = 600;   // TODO: khop voi gia tri dang dung trong firmware chinh
const float LEAD_SCREW_PITCH_MM = 8.0;

const int TABLE_DIR_LEVEL = HIGH;      // giong scan.cpp
const int Z_UP_LEVEL      = HIGH;      // giong scan.cpp

const int TEST_REVS               = 1;
const int PAUSE_BETWEEN_CYCLES_MS = 3000;

const float Z_TEST_MAX_MM = 150.0;

long  mmToSteps(float mm)   { return (long)(mm / LEAD_SCREW_PITCH_MM * TOTAL_STEPS_PER_REV + 0.5f); }
float stepsToMm(long steps) { return steps * LEAD_SCREW_PITCH_MM / TOTAL_STEPS_PER_REV; }

const long Z_TEST_MAX_STEPS = mmToSteps(Z_TEST_MAX_MM);

long zPosSteps  = 0;       // vi tri Z tinh bang xung, 0 = luc cap nguon
bool halted     = false;   // true = vuot gioi han mem -> dung han, can reset board
int  cycleCount = 0;

void enableDrivers() {
  digitalWrite(PIN_TABLE_EN, LOW);
  digitalWrite(PIN_Z_EN, LOW);
}

void stepPulse(int stepPin) {
  digitalWrite(stepPin, HIGH);
  delayMicroseconds(5);              // A4988 can xung toi thieu ~1us
  digitalWrite(stepPin, LOW);
  delayMicroseconds(STEP_DELAY_US);
}

void halt(const char* msg) {
  halted = true;
  Serial.println();
  Serial.print("!!! LOI: ");
  Serial.print(msg);
  Serial.print("  z=");
  Serial.print(stepsToMm(zPosSteps), 2);
  Serial.println(" mm");
  Serial.println("!!! Motor DA DUNG va giu nguyen vi tri. Nhan nut RESET tren board de chay lai.");
}

void spinTable(bool forward, int revs) {
  Serial.print("TABLE");
  Serial.print(forward ? " quay THUAN " : " quay NGUOC ");
  Serial.print(revs);
  Serial.println(" vong...");

  const int backLevel = (TABLE_DIR_LEVEL == HIGH) ? LOW : HIGH;
  digitalWrite(PIN_TABLE_DIR, forward ? TABLE_DIR_LEVEL : backLevel);
  delayMicroseconds(5);              // A4988: DIR on dinh truoc canh len STEP

  long totalSteps = (long)revs * TOTAL_STEPS_PER_REV;
  for (long i = 0; i < totalSteps; i++) stepPulse(PIN_TABLE_STEP);
}

bool spinZ(bool up, int revs) {
  Serial.print("Z");
  Serial.print(up ? " LEN " : " XUONG ");
  Serial.print(revs);
  Serial.print(" vong (");
  Serial.print((long)revs * TOTAL_STEPS_PER_REV);
  Serial.println(" xung)...");

  const int downLevel = (Z_UP_LEVEL == HIGH) ? LOW : HIGH;
  digitalWrite(PIN_Z_DIR, up ? Z_UP_LEVEL : downLevel);
  delayMicroseconds(5);

  long steps = (long)revs * TOTAL_STEPS_PER_REV;
  for (long i = 0; i < steps; i++) {
    if (up && zPosSteps >= Z_TEST_MAX_STEPS) { halt("VUOT GIOI HAN TREN (Z_TEST_MAX_MM)"); return false; }
    if (!up && zPosSteps <= 0)               { halt("VUOT GIOI HAN DUOI (thap hon vi tri luc cap nguon)"); return false; }
    stepPulse(PIN_Z_STEP);
    zPosSteps += up ? 1 : -1;
  }
  return true;
}

void setup() {
  Serial.begin(115200);
  delay(500);

  pinMode(PIN_TABLE_STEP, OUTPUT);
  pinMode(PIN_TABLE_DIR,  OUTPUT);
  pinMode(PIN_TABLE_EN,   OUTPUT);
  pinMode(PIN_Z_STEP,     OUTPUT);
  pinMode(PIN_Z_DIR,      OUTPUT);
  pinMode(PIN_Z_EN,       OUTPUT);

  enableDrivers();

  Serial.println();
  Serial.println("=== Test on dinh A4988 + dong co buoc (tu chay, khong can nut) ===");
  Serial.print("Cau hinh: ");
  Serial.print(TOTAL_STEPS_PER_REV);
  Serial.print(" xung/vong (");
  Serial.print(MOTOR_STEPS_PER_REV);
  Serial.print(" full-step x 1/");
  Serial.print(MICROSTEPPING);
  Serial.println(" microstepping)");
  Serial.print("STEP_DELAY_US = ");
  Serial.print(STEP_DELAY_US);
  Serial.print(" us   |   Moi chu ky quay ");
  Serial.print(TEST_REVS);
  Serial.println(" vong lien tiep moi chieu, lap lai lien tuc");
  Serial.println("Danh dau 1 diem tham chieu tren truc dong co TRUOC KHI cap nguon.");
  Serial.println("Vi tri Z luc cap nguon = z=0: truc Z chi di LEN roi ve, khong xuong thap hon.");
  delay(2000);
}

void loop() {
  if (halted) {          // da vuot gioi han mem: dung yen cho reset
    delay(1000);
    return;
  }

  cycleCount++;
  Serial.println();
  Serial.print("===== CHU KY #");
  Serial.print(cycleCount);
  Serial.println(" =====");

  Serial.println("--- BAN XOAY ---");
  spinTable(true, TEST_REVS);
  delay(500);
  spinTable(false, TEST_REVS);
  Serial.println("TABLE xong -- kiem tra diem danh dau da ve DUNG vi tri ban dau chua.");

  delay(1000);

  Serial.println("--- TRUC Z ---");
  if (!spinZ(true, TEST_REVS)) return;
  delay(1000);
  if (!spinZ(false, TEST_REVS)) return;
  Serial.println("Z xong -- kiem tra diem danh dau da ve DUNG vi tri ban dau chua.");

  Serial.print("Chu ky #");
  Serial.print(cycleCount);
  Serial.println(" hoan tat. Nghi truoc khi lap lai...");
  delay(PAUSE_BETWEEN_CYCLES_MS);
}

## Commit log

2026-09-07 Add 3D-printed frame documentation and reference images
    [Base_body.stl, Carriage.stl, Coupler.stl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]
2026-09-15 Add file readme of codetest and circuit
2026-09-20 Update ESP32-S3 scanning maincode
2026-09-22 add circuit
2026-10-12 ADD PCB layout
2026-10-12 Add image pcb and schematic
2026-10-27 fix file readme of Electrical Circuit
2026-10-28 Add real photos of the frame to the README
2026-10-28 Add and update PCB images
2026-10-28 Update frame model
2026-10-28 Update contain of Weekly Progress Report — week 4,5,6
2026-10-28 rename some image PCB
